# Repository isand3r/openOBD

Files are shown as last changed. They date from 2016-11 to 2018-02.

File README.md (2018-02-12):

# openOBD 
- An open-source vehicle telemetry system based on the [Raspberry Pi 0](https://www.raspberrypi.org/blog/raspberry-pi-zero) that supports OBD-2 and includes several sensors
- Originally developed as a UBC ECE [Capstone Project](https://www.ece.ubc.ca/courses/capstones) for [Mojio](https://www.moj.io/)

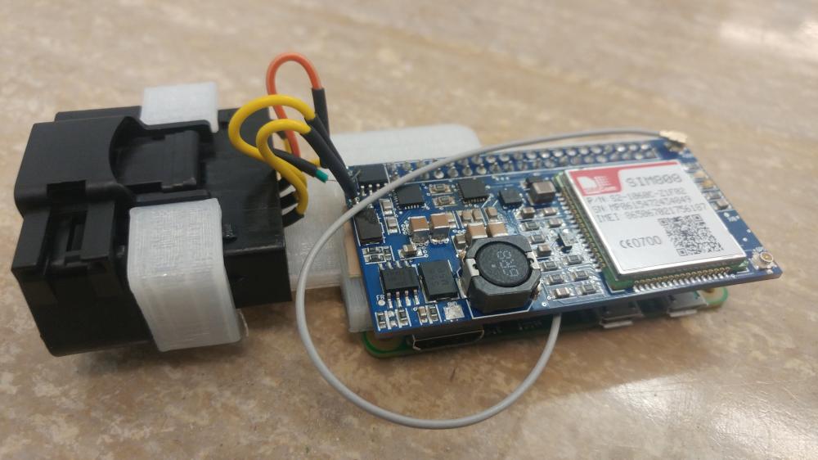
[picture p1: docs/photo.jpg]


### Setup

#### 1. Set up the Raspberry Pi

Follow this guide: https://www.raspberrypi.org/documentation/installation/installing-images/

The software requires a Linux-based operating system such as Ubuntu or Raspbian.

#### 2. Attach the board

Should be straightforward - attach the board using the GPIO socket with the board hanging overtop of your rpi.

#### 3. Clone this repository
On your raspberry pi, using the command line, run `git clone https://github.com/isand3r/openOBD`.

The Command line interface to get values from the sensors can be run using the file `app.py`

#### 4. Install dependencies

See the dependencies list at the bottom.

#### 5. Set up GSM (Optional)

Data readings can be saved to a file and uploaded via wifi, or for constant connectivity, there is a GSM module included.
All info on the GSM module can be found here: https://learn.adafruit.com/adafruit-fona-808-cellular-plus-gps-breakout/downloads#datasheets-and-app-notes

## Usage

### Command Line Application
```
cd software/openobd/
python3 app.py
```

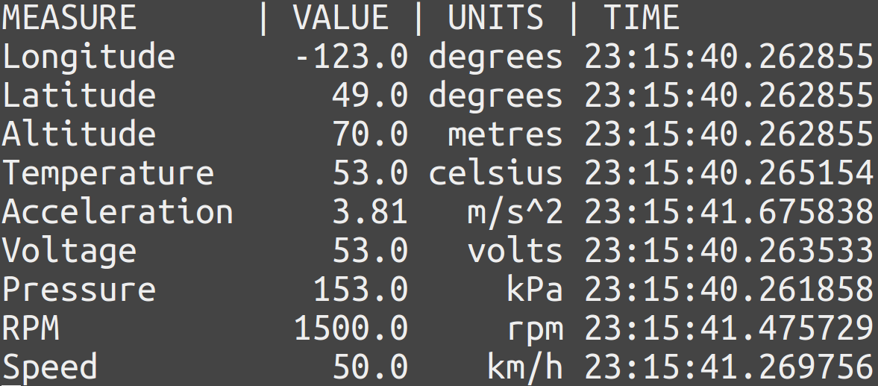
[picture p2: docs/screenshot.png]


### Configuration File
The configuration file `software/openobd/configuration/config.ini` (parsed using [configparser](https://docs.python.org/3/library/configparser.html)) is used to select the class that will be used for each sensor device (GPS, thermometer, etc). If mock devices are used (and if a few `import` lines are commented out in `software/openobd/app.py`), the command line application can be run on a regular PC without requiring the openOBD hardware.

### Tests
```
cd software/openobd/
python3 -m pytest
```

## Dependencies
Python packages (`pip3 install package-name`):
* `pytest` (doc.pytest.org/en/latest/)
* `RPi.GPIO` (https://pypi.python.org/pypi/RPi.GPIO)
* `PySerial` (https://pythonhosted.org/pyserial/)
* `python-can` (https://python-can.readthedocs.io)

## Contributors
* Nicholas Mulvenna
* Isaiah Thiessen
* Ehsan Ahmadi
* Kaibo Ma
* Rob Chartier

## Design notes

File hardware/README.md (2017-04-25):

### openOBD Hardware

The files in this folder are all contained in an Altium project. To view the files, you will need either Altium Designer or other compatible software (newer versions of [Eagle](http://www.autodesk.com/products/eagle/overview) can import Altium projects).

#### Circuit Schematics (Images) (coming soon)

#### B.O.M. (coming soon)

#### Programming the on board microcontroller

The on board microcontroller (ATtiny25) is wired to sense the vehicles battery voltage using its ADC. It can in turn controll a switch that can short the RUN pins on the Raspberry Pi Zero and wake/reboot it. The Raspberry Pi can communicate with the microcontroller through SPI interface in order to retreive data and/or reprogram it. This setup provides the user flexibility in implementing a custom power management. Following the instructions below, the ATtiny can be easily programmed:

* Compile your program using your favourite IDE/compiler ([Arduino IDE](http://www.arduino.org/downloads) or [Atmel studio](http://www.microchip.com/development-tools/atmel-studio-7) are options)
* Locate the generated .hex file and transfer it to the Raspberry Pi ([winSCP](https://winscp.net/eng/download.php) is a good tool)
* On the pi run 'sudo apt-get install avrdude' 
* [Configure](www.google,ca) avrdude using the following settings
1. 
    * id=pi0;
    * desc  = "Use the Linux sysfs interface to bitbang GPIO lines";
    * type = "linuxgpio";
    * reset = 18;
    * sck = 21;
    * mosi = 20;
    * miso = 19;

#### PCB Manufacturer

For our PCB, we used [pcbway.com](https://www.pcbway.com/). They are cheap, fast, and reliable. (images coming soon)

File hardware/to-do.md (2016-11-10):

## Hardware To-Do list

### Schematics

Additions:

  * Add gps chip & necessary power components
  * Add MEMs Sensor chip & necessary power components
  * Add a PCB layout

Changes:

  * Wire up the Mux
  * Wire up above components/chips once added

### Documentation

  * Create more documentation!

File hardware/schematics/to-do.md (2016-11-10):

## Hardware Schematics To-Do list

Additions:

  * Add gps chip & necessary power components
  * Add MEMs Sensor chip & necessary power components

Changes:

  * Wire up the Mux
  * Wire up above components/chips once added

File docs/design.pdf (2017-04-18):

# openOBD

# Automotive Telematics Unit

# Design - v3.3

## Authors:

## - Nicholas Mulvenna

## - Kaibo Ma

## - Ehsan Ahmadi

## - Isaiah Thiessen

Table of Contents

History of Revisions | 3
List of Figures and Tables | 6
1 - Introduction | 7
1.1 - How to Use this Document | .
2 - High-Level Architecture | 8
2.1 - Hardware Architecture | .
2.2 - Software Architecture | 10
3 - Low Level Design | 12
3.1 - Hardware Components | .
3.1.1 - Raspberry Pi Zero | .
3.1.2 - CAN Node | .
3.1.2A - MCP2515 CAN Controller | .
3.1.2B - TCAN332 CAN Transceiver | 13
3.1.3 - Power Supply | .
3.1.4 - Sensor Inputs | 14
3.1.4A - Sim808 GSM + GPS Cellular Module | .
3.1.4B - MPU6050 MEMs Motion Sensor Breakout Board | .

3.1.4C - ATtiny25 Microcontroller

3.1.5 - Printed Circuit Board (PCB) Design | .

3.1.6 - Hardware Enclosure | 15
3.2 - Software Components | .
3.2.1 - Python 3 | .
3.2.2 - Dependency Inversion Principle | 16
3.2.3 - Single Responsibility Principle | 17
4 - Conclusion | .
References | 18
Appendix I - On Board Diagnostics - OBD II | 20
Appendix II - Controller Area Network - CAN | .
Appendix III - Circuit Diagrams | 22
Appendix IV - Prototype Hardware Setup | 24
Appendix V - Sim808 Connections | 25
Appendix VI - MPU6050 Connections | .
Appendix VII - Printed Circuit Board - PCB | 26
Appendix VIII - PCB Layout Considerations | 27
Appendix IX - CAN Node Connections | 28
Appendix X - Live OBD2 Readings for Speed and RPM | 29
Appendix XI - Complete Hardware Setup | 30

History of Revisions

Version | Authors | Date | Changes
1.0 | Isaiah Thiessen Kaibo Ma Nicholas Mulvenna Ehsan Ahmadi | 2016-11-28 | Initial Draft
1.1 | Isaiah Thiessen | 2017-02-13 | - Updated Hardware Architecture diagram - Changed GPS section to reflect new chip being used - Updated Appendix V with new chip information
1.2 | Ehsan Ahmadi | 2017-02-13 | - New Can transceiver chip - Remove level shifter - New power supply - Added appendix VIII
1.3 | Isaiah Thiessen | 2017-02-13 | - Added component schematics in Appendix III (changed heading to Circuit Diagrams) - Added Appendix VII - PCB design schematic - Added Section 3.1.5 - PCB - Added Appendix IX for the CAN node pinout
1.4 | Nicholas Mulvenna | 2017-02-13 | - Updates software section with details on Manager and Configuration classes

| | | - Edited sections on dependency inversion and single responsibility principles - Removed abstraction layers section
2.0 | Isaiah Thiessen Ehsan Ahmadi Nicholas Mulvenna Kaibo Ma | 2017-02-13 | Final edits before v2 document release with some added figures to appendix
2.1 | Nicholas Mulvenna | 2017-02-26 | Corrects overlapping lines in high-level UML class diagram
3.0 | Nicholas Mulvenna | 2017-03-18 | - Style and wording in various sections - Describes the DeviceCollection class and removes references to the Shell class - Simplifies the high-level UML class diagram and adds new diagrams for the DeviceCollection and Manager classes
3.1 | Isaiah Thiessen | 2017-04-02 | - Justified amperage in power supply section - Fixed mistaken section heading in t.o.c. - New Hardware architecture Diagram

| | | - Edited section numbers - Added hardware enclosure section and appendix
3.2 | Ehsan Ahmadi | 2017-04-03 | - Updated power supply section to reflect new design - Added attiny25 section and schematic - Updated current/complete hardware setup - Updated list of tables & fig
3.3 | Nicholas Mulvenna | 2017-04-17 | - Changes to wording

List of Figures and Tables

Figure 2.0: High-Level Hardware Architecture | 8
Figure 2.1: UML class diagram focused on the App class | 10
Figure 2.2: UML class diagram focused on the DeviceCollection class | 11
Figure 2.3: UML class diagram focused on the Manager class | 11
Table 3.0: Python 2 vs Python 3 | 16
Figure A1.0: CAN bus diagram | 21
Figure A3.0: CAN Node Circuit Diagram | 22
Figure A3.1: SIM808 Circuit Diagram | .
Figure A3.2: Power Circuit Diagram | 22
Figure A3.3: MPU6050 Circuit Diagram | 23
Figure A3.4: ATtiny circuit diagram | 24
Figure A4.0: Prototype Hardware Setup | .
Table A5.0: Sim808 Module Connections | 25
Table A6.0: Motion Sensor Module Connections | .
Figure A7.0 - Printed Circuit Board Layout | 26
Figure A8.0 Buck converter topology and current loops | 27
Table A9.0: CAN Node to Raspberry Pi Connections | 28
Table A9.1: CAN Node to OBD-II Connections | .
Figure A10.0 - Live RPM readings from Revving Toyota Camry Engine | 29
Figure A10.1 - Log for Accelerating on Toyota Camry | 30
Figure A11.0 - Final setup assembled with the enclosure | .

1 - Introduction
This document is a comprehensive map of the technical design choices used in developing the Automotive Telematics Unit.

### 1.1 How to Use this Document

Aside from section 2, this document is of a highly technical nature. For both the technical or non-technical reader, section 2.0 - High-Level Architecture for hardware and software is the recommended starting point.

Following the high level discussion is a low-level technical breakdown of each component in section 3: Low-Level Design. Each subsection provides the reasoning behind the design choices, and guides the reader to a corresponding set of relevant appendices where various design artifacts are presented.
Subsection 3.1 covers hardware components, while 3.2 discusses software design.

2 - High-Level Architecture

2.1 - Hardware Architecture
Looking at figure 2.0, one can understand the hardware components involved as well as how each interacts within the design. Photos of the setup, in prototype stage are shown in Appendix IV, while Appendix XI shows the complete setup.

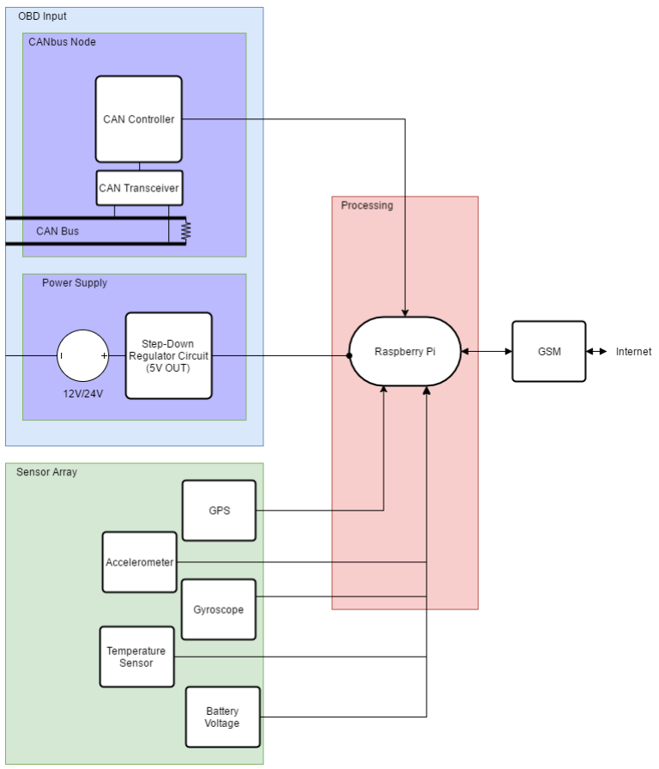
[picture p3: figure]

Figure 2.0: High-Level Hardware Architecture

On the following page is a brief description of the function of each component.

Processing Component:
A Raspberry Pi Zero interfaces with sensors and the OBD input block to collect, parse, and process the data.

OBD Input - CAN bus Component:
A CAN Bus device, following the CAN standard, includes a CAN controller and transceiver in order to read and write data to the CAN bus and perform arbitration and identification. It communicates with the processing block over a serial peripheral interface. The CAN bus is chosen as the focus of this project since every vehicle produced in the US since 2008 implements it.

OBD Input - Power Component:
Power for the processing block is drawn from the OBD port at 12 or 24 volts, depending on the vehicle. A power converter is used to regulate the power down to the levels required by the system

Sensors Component:
An array of onboard sensors for motion, temperature, and location readings.

A low level breakdown of each component is provided in section 3.1.

2.2 - Software Architecture
Our architecture, described in the UML class diagram in figure 2.1, is based on abstract classes. Our main executable class App instantiates our concrete device classes (based on a configuration file) and aggregates them in a DeviceCollection instance. Also, it instantiates the Manager class which automatically reads, interprets, and displays data. App provides Manager with the DeviceCollection (an implementation for an IDeviceCollection) to allow it to read data from our sensors and the OBD port. Since our major components are all constructed by App, Manager and DeviceCollection depend on abstract classes instead of being coupled to specific implementations.

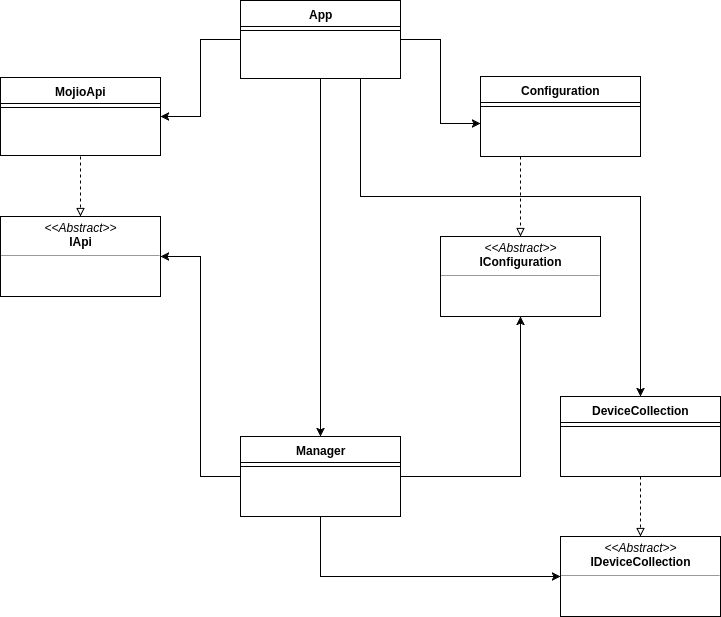
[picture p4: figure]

Figure 2.1: UML class diagram focused on the App class

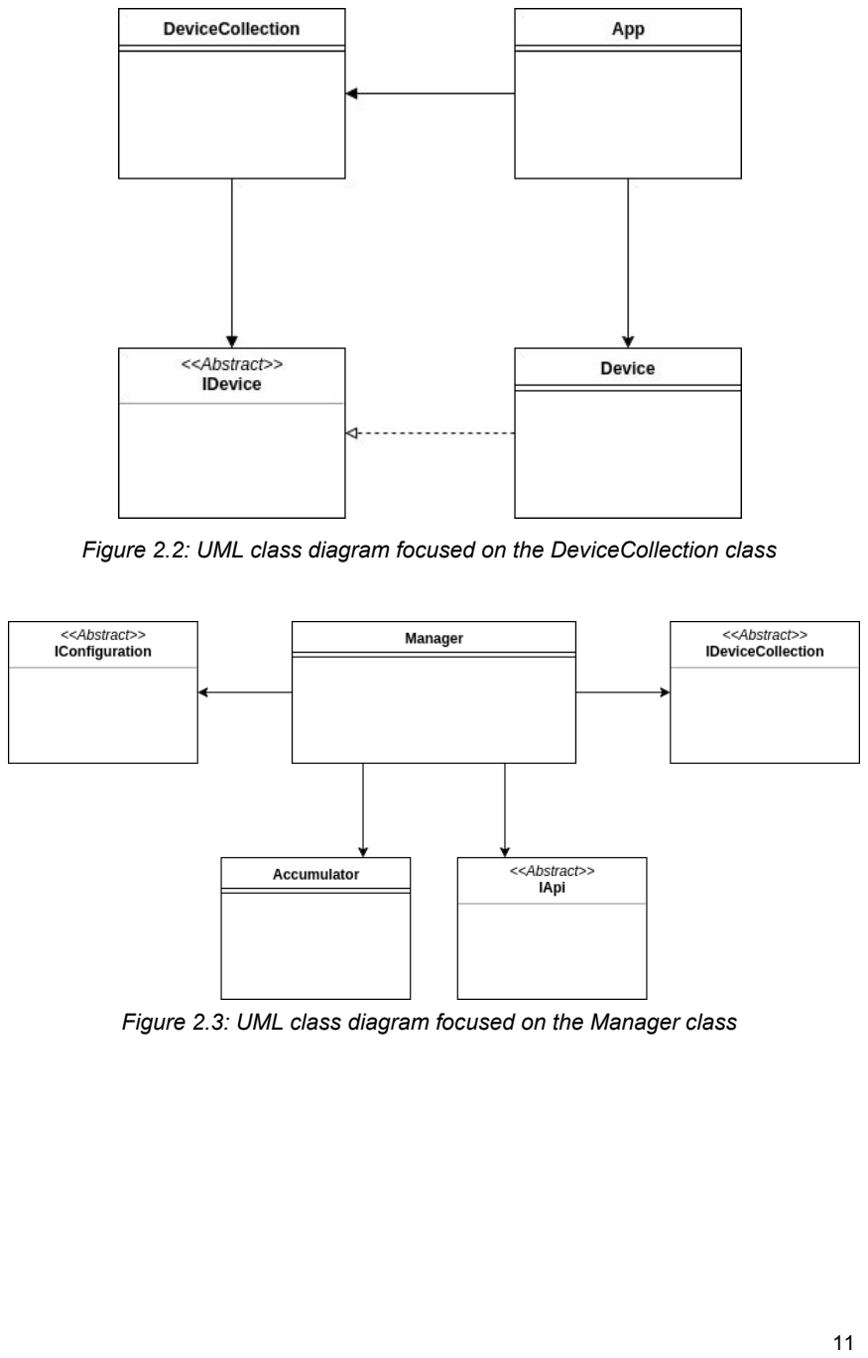
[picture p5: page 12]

Figure 2.2: UML class diagram focused on the DeviceCollection class

Figure 2.3: UML class diagram focused on the Manager class

3 - Low-Level Design
The next sections go into detail around the design choices of each component. In order to justify these choices, references are made to functional specifications (coded FS##), non-functional specifications (coded NS##), and constraints (coded C##) which are defined in the accompanying requirements document.

3.1 - Hardware Components

3.1.1 - Raspberry Pi Zero
The Raspberry Pi Zero is a small, inexpensive single board computer used as the main processing unit of the system. It runs a 1GHz ARM processor, supported by 512MB of ram, providing plenty of processing power. An array of GPIO pins with SPI, I2C and UART capabilities makes interfacing with sensors and hardware components very easy and satisfies the FS02 specification. The Pi Zero is widely adopted by the open source community globally and extensively documented. This means open source libraries are available for almost any application and support is readily accessible resulting in short development ramp-up time. The Pi Zero runs Raspbian Jessie (A Debian Linux based operating system optimized for the Pi) which provides a terminal interface to the user over USB, satisfying the FS03 specification.

3.1.2 - CAN Node
The CAN node implements the standard CAN communication protocol and facilitates interfacing with the CAN bus and satisfying FS01. It gives the system access to the vehicle’s on board diagnostics (OBD-II) network which can provide information about and control over different components of the vehicle. The CAN node is comprised of a CAN controller, CAN transceiver and two level converters A detailed description of the OBD-II and CAN are provided in appendix I and II respectively. See Appendix III for a circuit diagram and pinout information.

3.1.2A MCP2515 CAN Controller
As detailed in Appendix I the CAN communication protocol implements error correction, bit timing, and synchronization and arbitration of different nodes on the

CAN bus. To achieve this, complex message frames are used to transmit data on the can bus. The CAN controller acts as a configurable node on the can bus and deals with the low level implementation of the CAN protocol. It extracts the data contained in a CAN message frame received from the bus and provides it to the processor over an SPI interface. It can also convert data provided by the processor and converts it to a CAN message frame that is ready to be transmitted on the bus. This chip was chosen as it provides the best combination of functionality and low cost, and is commonly used in the design of CAN devices. [7]

3.1.2B TCAN332 CAN Tranceiver
CAN message frames provided by the can controller as a serial signal of ones and zeros is converted to a differential signal and transmitted on the CAN bus (appendix
I) by the CAN transceiver. At the same time differential signals received on the can bus are converted to a serial signal and provided to the CAN controller. This chip was chosen as it provides the best combination of functionality and low cost. Since the chip uses 3.3 volts, it uses less power the need for level shifting between it and the controller is eliminated resulting in a smaller pcb footprint.[8]

3.1.3 - Power Supply
An LMR16030 Buck controller, combined with external components (7 capacitors, Inductor, a Diode and a few resistors) is used as the power supply. The power supply is designed for a wide input voltage range of 6V to 40V. It steps down voltage from the OBD port (typically 12V or 24V) to a constant 5V to power the Pi Zero which in turn powers all the other components with the exception of the sim808 (powered through a 5V to 4V linear regulator), satisfying the FS07 requirement. The power supply is designed to provide up to 3A (15W). 1A is required by the Pi to function reliably [16] leaving enough power for the sim808 chip which peaks at 2A. The LMR16030 is a flexible converter with an internal high side mosfet running at 500KHz, providing the ability to use very small external components, saving both space and cost. A switching supply is used instead of a linear regulator in order to reduce power losses and prevent excessive heating, in line with C04 and C06.

3.1.4 - Sensor Inputs

3.1.4A - Sim808 GSM + GPS Cellular Module
The Sim808 module was chosen in order to reduce footprint consumption for the PCB design, while retaining ease-of-setup and short development overhead. This component provides all necessary GPS location functionality over UART to the processing unit in a “plug-and-play” fashion at relatively low cost, in addition to providing 2G Cellular network connectivity. See Appendix V for pinout information and links to official documentation.

3.1.4B - MPU6050 MEMs Motion Sensor Breakout Board
The MPU6050 was chosen with the same justifications as the Adafruit GPS board discussed above. It provides accelerometer, gyroscope and temperature data to the processing unit over I2C. See Appendix VI for pinout information and links to official documentation.

3.1.4C - ATtiny25 Microcontroller
One of the limitations of the Pi is that it does not include an ADC (analog to digital converter). To overcome this limitation, a cheap ATtiny25 microcontroller was added to the design. Some desired functions of the ATtiny include ADCs, SPI communication and general purpose GPIOs. The ATtiny senses the voltage of the vehicle’s battery and makes it available to the Pi over SPI. It is also able to safely shut down and turn on the Pi. The ATtiny runs independent of the Pi, however, it can be programmed on-the-go using the Raspberry Pi, making it a very flexible and customizable power management solution.

3.1.5 - Printed Circuit Board (PCB) Design
The design schematic for the PCB layout is included in Appendix VII. It was designed to approximately match the form factor of the Raspberry Pi Zero in order to minimize the overall size of the device. Further technical information is included with the schematic. All values for items such as minimum hole size, trace size and spacing, were chosen in order to meet the capabilities of the PCB manufacturer while achieving the desired form factor. Since the PCB combines a high frequency switching power supply and multiple high speed communication devices in a small area. Strict guidelines were followed when laying out the board in order to ensure signal integrity and reliable communication. These guidelines were It is highly recommended to follow these guidelines detailed in appendix X when reproducing the PCB with minor modifications. The pcb has an exposed ground pad as well as several test points for the output and feedback pin of the power supply, 4V linear regulator, SPI data lines, as well as multiple power rails of the Sim808 chip. As a result, an oscilloscope can be easily attached in order to debug the circuit if need be.

3.1.6 - Hardware Enclosure
Given that this is an open-source, modular project, an example hardware enclosure is shown in Appendix XI. This part’s design would be modified depending on changes made to the hardware.
The example design was chosen for simplicity and ease of fabrication. It holds all of the components together and provides a grip point for ease of setup or removal.

### 3.2 Software Components

3.2.1 - Python 3
Python 3 is a robust and popular language. There is significant community-based documentation and a wide variety of available modules. Python also includes convenient Cmd and ConfigParser classes that we use for debugging and in our Configuration class implementation.

In addition, our team has picked Python 3 over Python 2. In the following Table, key main differences between the two versions and why we believe Python 3 is more advantageous:

Python 2.7.12 | Python 3.5.2
- Legacy - Will have no more major feature releases | - Long term supported version - Present and future of the language - Ongoing expansions and support for the language

Table 3.0: Python 2 vs Python 3

3.2.2 - Dependency inversion principle
In object oriented programming, there are various types of branches of design principles. One of which is dependency inversion principle. This refers to the decoupling between different software modules. In other words, two different libraries are not dependent on each other. When following this principle, higher level classes/modules will be independent from lower level modules implementation details. For our project, that means that our Manager class (through its DeviceCollection) depends only on abstract classes for devices. This allows different device class implementations to be substituted without requiring any changes to classes such as the DeviceCollection, MojioApi, and Manager. In future prototypes and products, it will be easier to change hardware modules (such as our GPS or sensors) because only the module/class responsible for that hardware’s drivers need to be modified and not the entire application. Software modules can be extracted and placed in a whole new application without worrying about dependencies of a particular module being extracted. This allows a “plug and play” convention for mixing and matching modules. For example, we could extract the modules for GPS and import them in a completely unrelated project that uses the same GPS hardware.
Our architecture is based on abstract classes to fulfill requirement NS02. Python supports multiple inheritance so it does not have Java-style interfaces. To ensure that they cannot be instantiated, our abstract classes extend the abc.ABC class.[14]

This is equivalent to an interface-oriented architecture because our abstract classes do not contain implementations.

3.2.3 - Single responsibility principle
This is a principle in object oriented design which states that modules, classes, and functions should only have one responsibility or purpose within the software. The functionality should be completely encapsulated within the class or function. For example, the device classes are responsible only for taking readings from the hardware modules but not for working with those readings. Similarly, the Manager class decides when to take readings and displays them to the user but does not directly interact with the hardware. Indirectly, this principle enforces the dependency inversion principle as well.

4 - Conclusion
The overall design and theme of the product is based on community learning. Both hardware and software use open source solutions and libraries. As a result our project will also be open source with a public repository for anyone else to access.

Our hardware and software are tailored for customizability. The hardware can be interchanged with relative ease because the software adopts the single responsibility and dependency inversion principles. This allows modularity and independence of different modules and devices like OBD and GPS. Hardware can be swapped out for faster and even better devices with minimal changes to the software.

References
[1] Guttag, John V. (2013-01-18). Introduction to Computation and Programming Using Python (Spring 2013 ed.). Cambridge, Massachusetts: The MIT Press. ISBN (https://en.wikipedia.org/wiki/International_Standard_Book_Number) 9780262519632. (https://en.wikipedia.org/wiki/Special:BookSources/9780262519632)
[2] "Abstract Methods and Classes". (http://docs.oracle.com/javase/tutorial/java/IandI/abstract.html) The Java™ Tutorials. Oracle. Retrieved 27 November 2016.
[3]"Dissection of the Single Responsibility Principle - dylanwilson.net", Dylanwilson.net, 2016. [Online]. Available: http://www.dylanwilson.net/dissection-of-the-single-responsibility-principle. [Accessed: 27- Nov- 2016].
[4] "Dependency Inversion Principle | Object Oriented Design", Oodesign.com, 2016.
[Online]. Available: http://www.oodesign.com/dependency-inversion-principle.html. [Accessed: 27- Nov- 2016].
[5] “Should I use Python 2 or Python 3 for my development activity?”, wiki.python.org, 2016. [Online]. Available: https://wiki.python.org/moin/Python2orPython3 [Accessed: 27- Nov- 2016].
[6] “MPU-6000 and MPU-6050 Product Specification Revision 3.4”, Sparkfun, 2016. [Online]. Available:
http://43zrtwysvxb2gf29r5o0athu.wpengine.netdna-cdn.com/wp-content/uploads/2015/02/MPU-6000-Datasheet1.pdf (http://43zrtwysvxb2gf29r5o0athu.wpengine.netdna-cdn.com/wp-content/uploads/2015/02/MPU-6000-Datasheet1.pdf) [Accessed: 27-Nov-2016]
[7] “Stand-Alone CAN Controller with SPI Interface”, microchip.com, 2016. [Online]. Available: http://ww1.microchip.com/downloads/en/DeviceDoc/21801G.pdf [Accessed: 27-Nov-2016]
[8] “High-Speed CAN Transceiver”, microchip.com, 2016. [Online].
Available: http://ww1.microchip.com/downloads/en/DeviceDoc/20005167C.pdf [Accessed: 27-Nov-2016]
[9] “Adafruit Ultimate GPS Breakout - 66 Channel W/10 HZ Updates”, adafruit.com, 2016. [Online]. Available: https://www.adafruit.com/product/746 [Accessed: 27-Nov-2016]
[10] “Triple Axis Accelerometer Gyro Breakout MPU6050 v12”, sparkfun.com, 2016. [Online]. Available:

https://cdn.sparkfun.com/datasheets/Sensors/IMU/Triple_Axis_Accelerometer-Gyro_Breakout_-_MPU-6050_v12.pdf (https://cdn.sparkfun.com/datasheets/Sensors/IMU/Triple_Axis_Accelerometer-Gyro_Breakout_-_MPU-6050_v12.pdf) [Accessed: 27-Nov-2016]

[11] “GPS_FGPMMOPA6H_v0.3”, adafruit.com, 2016. [Online]. Available:

https://cdn-learn.adafruit.com/assets/assets/000/022/494/large1024/gpssch.png?142153647 5 (https://cdn-learn.adafruit.com/assets/assets/000/022/494/large1024/gpssch.png?1421536475) [Accessed: 27-Nov-2016]
[12] “Introduction to the Controller Area Network (CAN)”, ti.com, 2008. [Online]. Available: http://www.ti.com/lit/an/sloa101a/sloa101a.pdf [Accessed: 27-Nov-2016]
[13] “On-board diagnostics”, Wikipedia, The Free Encyclopedia, 2016. [Online]. Available: https://en.wikipedia.org/wiki/On-board_diagnostics#SAE_standards_documents_on_OBD-II (https://en.wikipedia.org/wiki/On-board_diagnostics#SAE_standards_documents_on_OBD-II) [Accessed: 27-Nov-2016]
[14] "Abstract Base Classes in Python – dbader.org", Dbader.org, 2016. [Online]. Available: https://dbader.org/blog/abstract-base-classes-in-python. [Accessed: 28-Nov-2016].
[15] “Switching Power Supply PCB Layout Considerations – Towards a Better Switcher”, optimumdesign.com, 2017/ [online]. Available: http://blog.optimumdesign.com/switching-power-supply-pcb-layout-considerations-to wards-a-better-switcher. (http://blog.optimumdesign.com/switching-power-supply-pcb-layout-considerations-towards-a-better-switcher) [Accessed: 13-Feb-2016]
[16] “Power Supply”, raspberrypi.org, 2017 / [online]. Available: https://www.raspberrypi.org/documentation/hardware/raspberrypi/power/README.m d (https://www.raspberrypi.org/documentation/hardware/raspberrypi/power/README.md) [Accessed: 02-Apr-2016]
[17] “Program an AVR...Raspberry Pi GPIO”, Adafruit.com, 2017 / [Online]. Available:
https://learn.adafruit.com/program-an-avr-or-arduino-using-raspberry-pi-gpio-pins/ov erview (https://learn.adafruit.com/program-an-avr-or-arduino-using-raspberry-pi-gpio-pins/overview) [Accessed: 03-Apr-2016]

Appendix I - On Board Diagnostics - OBD-II
Onboard diagnostics (OBD) is a computer based system built into all 1996 and later light-duty vehicles and trucks to monitor and in newer vehicles control their different sub components. The OBD-II standard defines the OBD II diagnostic connector and 5 standard communication protocols for interfacing with it, one of which is the CAN protocol and is standard on all US produced vehicles since 2008. The CAN is described in detail in appendix II and is the target protocol for this project. For more information on the OBD, see [13].

Appendix II - Controller Area Network - CAN
A Controller Area Network is defined by its two components described in this appendix, the CAN bus and the CAN communication protocol (ISO-11898). This appendix is based on ti’s introduction to CAN document [12] and introduces a few basics of the CAN in order to demonstrate its complexity. This complexity is handled by the MCP2515 CAN controller, however, a hardware designer needs to be aware of these complexities in order to use the controller.
The CAN bus is a multi-master, message broadcast system that specifies a
maximum signaling rate of 1 megabit per second (Mbps). As shown in figure A1, multiple masters (nodes) are connected to a differential line that is terminated by two resistors. Signals on the CAN bus are differential and highly immune to noise. A logic high is dominant and represents a 0, while a logic-low is recessive and represents a
1. This means that a 0 written on the bus by one node, overwrites a 1 that is simultaneously written by another node. This property is key to arbitration process described in the communication protocol. For effective communication, every node on the bus must agree to uniform nominal bitrate.

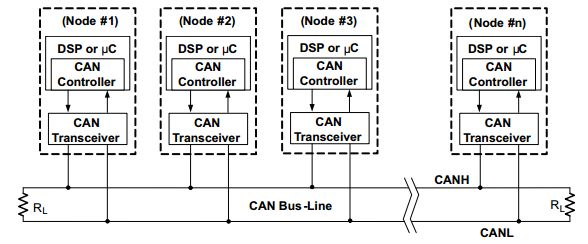
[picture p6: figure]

Figure A1.0: CAN bus diagram

The CAN communication protocol is a carrier-sense, multiple-access protocol with collision detection and arbitration on message priority (CSMA/CD+AMP). Since every node on the bus is a master and has read/write capability, each node on a bus must wait for a prescribed period of inactivity before attempting to send a message. Usage of the bus granted to the node that is transmitting a message with the highest priority. Messages are identified using a 11-bit (standard CAN) or 29-bit (extended CAN) identifier which allows for up to 2048 or 537 million unique prioritization levels respectively. Since the transmitted messages are broadcasted to all the nodes, the identifier can also be used to target the messages to specific nodes. The receiving nodes perform error checking on the message and requests a resend if failed. Due to different delays times and different clock speeds across the CAN, The actual bitrate of the messages is dynamically adjusted slightly above or below the nominal bit rate to keep the nodes synchronized and resolve errors

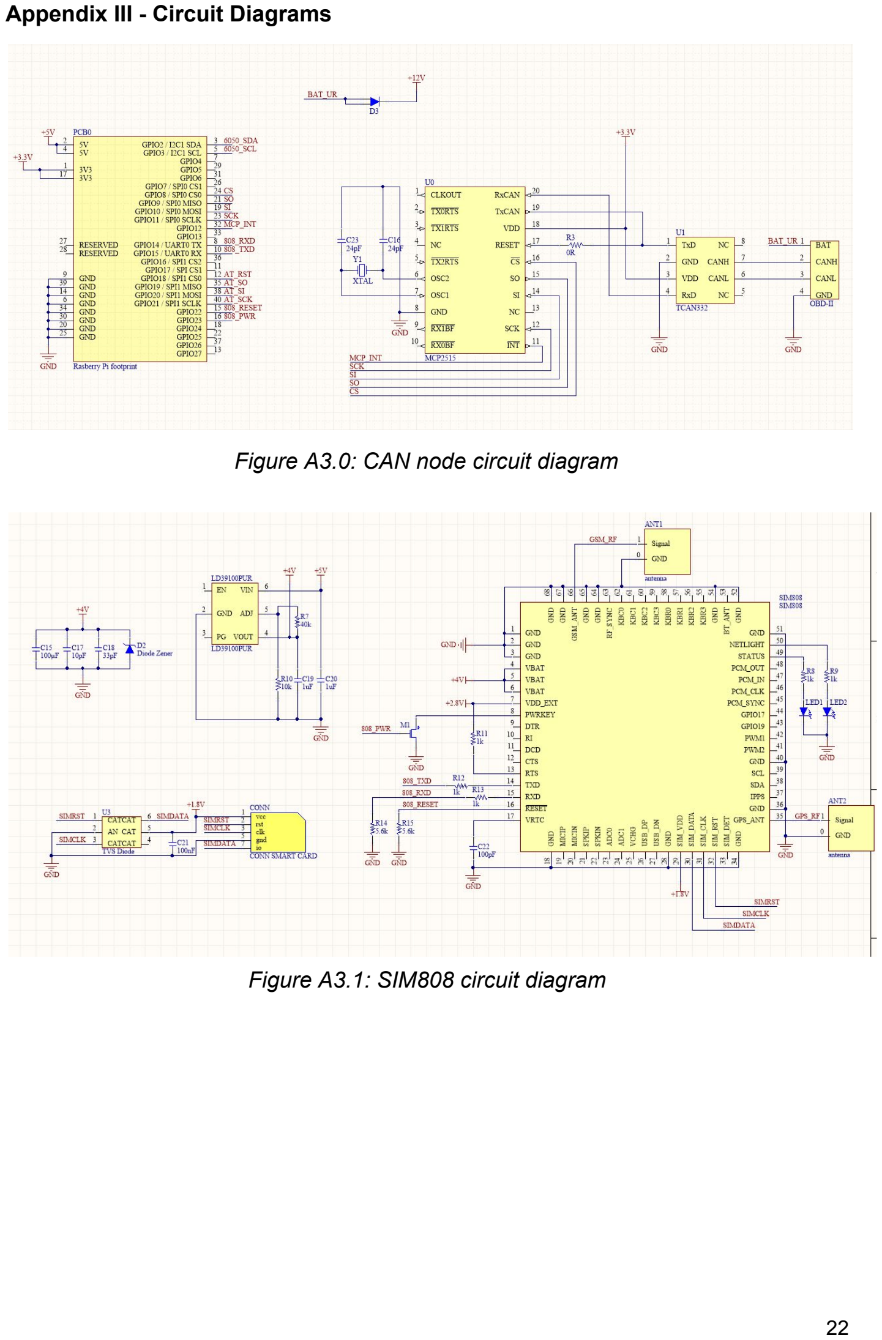
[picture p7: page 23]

Appendix III - Circuit Diagrams

Figure A3.0: CAN node circuit diagram

Figure A3.1: SIM808 circuit diagram

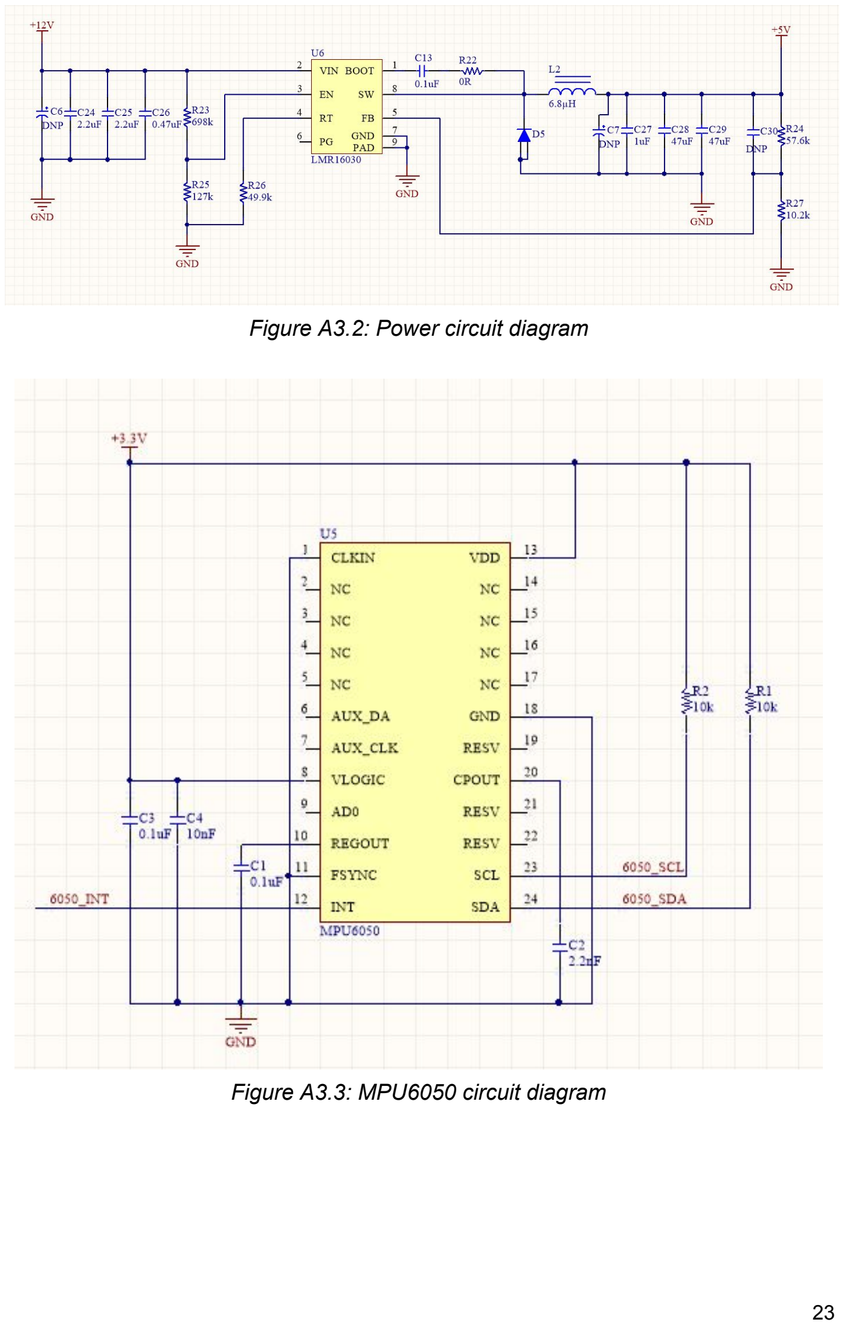
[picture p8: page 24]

Figure A3.2: Power circuit diagram

Figure A3.3: MPU6050 circuit diagram

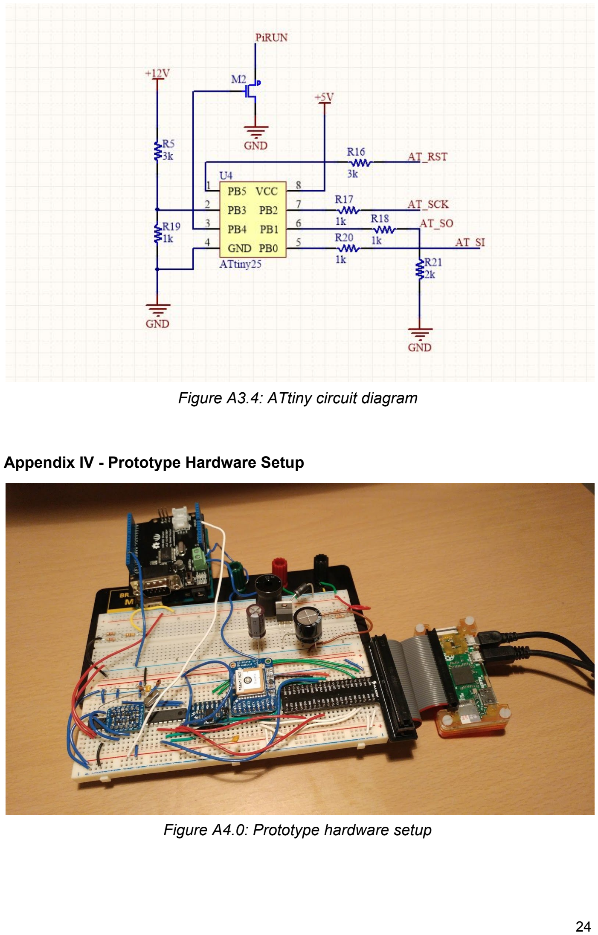
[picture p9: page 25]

Figure A3.4: ATtiny circuit diagram

Appendix IV - Prototype Hardware Setup

Figure A4.0: Prototype hardware setup

Appendix V - Sim808 Connections https://www.adafruit.com/product/2637

Sim808 Connections

Sim808 Pin | Raspberry Pi pin #
RESET | 15
PWR | 16
GND | 6
VIN | 2
TXD | 10
RXD | 8
Table A5.0: Sim808 module connections

Appendix VI - MPU6050 Connections

https://cdn.sparkfun.com/datasheets/Sensors/IMU/Triple_Axis_Accelerometer-Gyro_Breakout_-_MPU-6050_v12.pdf (https://cdn.sparkfun.com/datasheets/Sensors/IMU/Triple_Axis_Accelerometer-Gyro_Breakout_-_MPU-6050_v12.pdf)

MPU6050 Connections

MPU6050 Pin | Raspberry Pi pin #
VCC | 1
GND | 6
SCL | 5
SDA | 3
Table A6.0: Motion sensor module connections

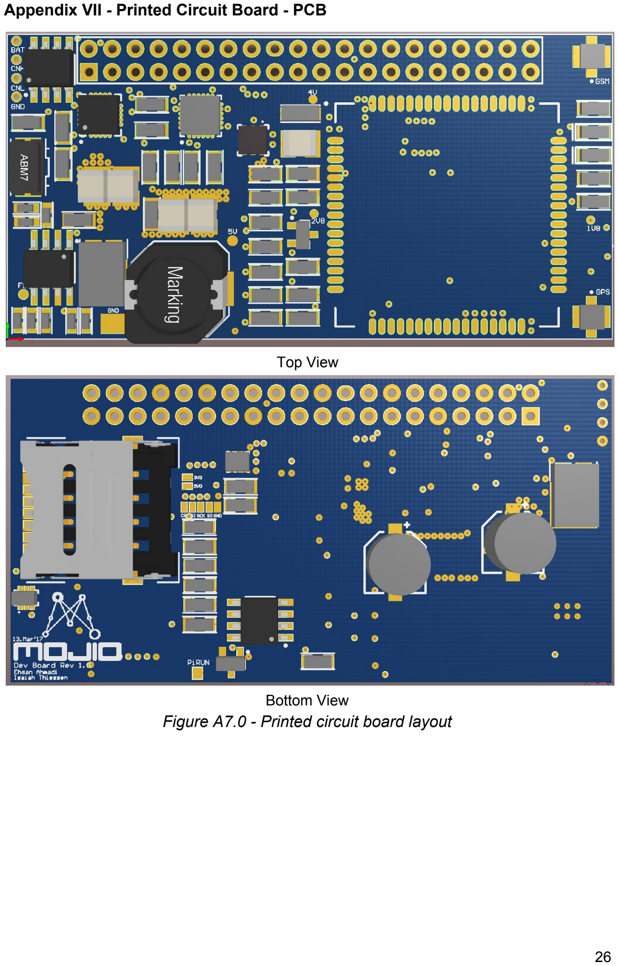
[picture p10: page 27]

Appendix VII - Printed Circuit Board - PCB

Top View

Bottom View
Figure A7.0 - Printed circuit board layout

Appendix VIII - PCB Layout Considerations

High frequency switching power supplies are efficient and flexible compared to linear regulators, however they can be a significant source of EMI (Electro-Magnetic Interference) which can corrupt low power signals in their vicinity resulting in a malfunctioning board. EMI generated by switching power supplies can be significantly reduced if the following guidelines are followed when laying out the design. The guidelines refer to figure A8.0 which shows the main AC and DC current loops in the buck converter topology.

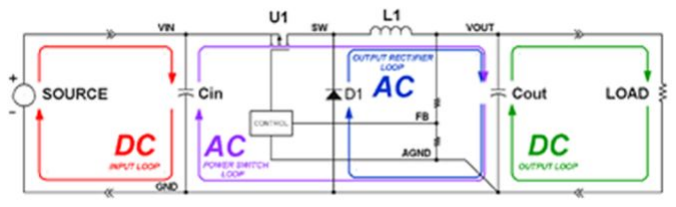
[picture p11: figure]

Figure A8.0 - Buck converter topology and current loops [15]

- The SW node carries a high frequency AC current of large magnitude and acts as an antenna, the main source of EMI. A good layout should minimizes the length of the switch node.
- For the AC currents, the length should be minimized with the forward paths on the top layer and the return paths on the bottom layer forming a closed loop. A ground plane on the bottom layer facilitates this.
- Lots of vias have to be used between layers for a low impedance path.
- The ground plane under the power supply should be separated from the signal ground(for the rest of the board) using a small connection in order to keep the high frequency currents contained.
- All the AC and DC loops should be laid out using polygons to ensure low impedance.
- The power supply should be placed as far as possible from sensitive signals, especially the GPS and GSM antennas.

Appendix IX - CAN Node Connections

To Raspberry Pi

Circuit Pin | Raspberry Pi Pin #
5V0 | 2
3V3 | 1
GND | 6
RESET | GND
CS | 24
SO | 21
SI | 19
STBY | Not currently Used
Table A9.0: CAN Node to Raspberry Pi Connections

OBD Connections

Circuit Pin | OBD Port Pin #
CAN HIGH | 6
CAN LOW | 14
BAT +12V | 16
GND | 5
Table A9.1: CAN Node to OBD-II Connections

Appendix X - Live OBD2 Readings for Speed and RPM

The following two images are from accelerating a Toyota Camry 2015 from resting and parking to about 21km/h.

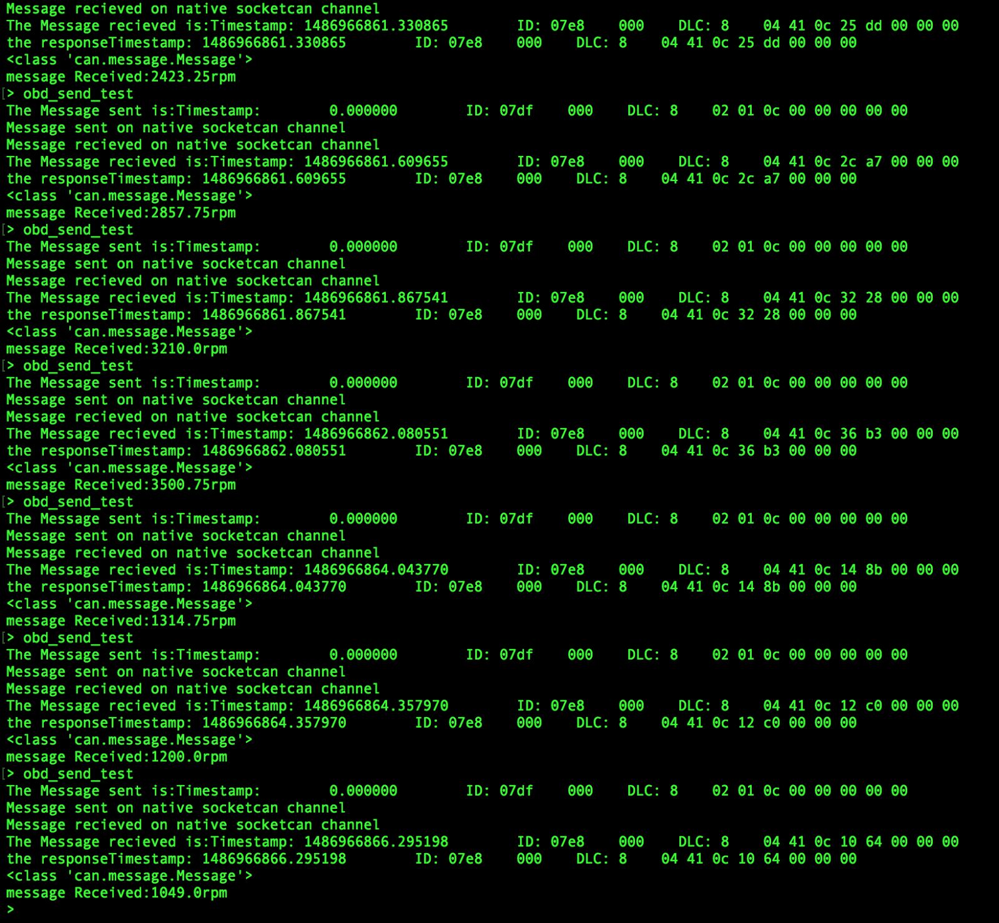
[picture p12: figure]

Figure A10.0 - Live RPM readings from revving Toyota Camry engine

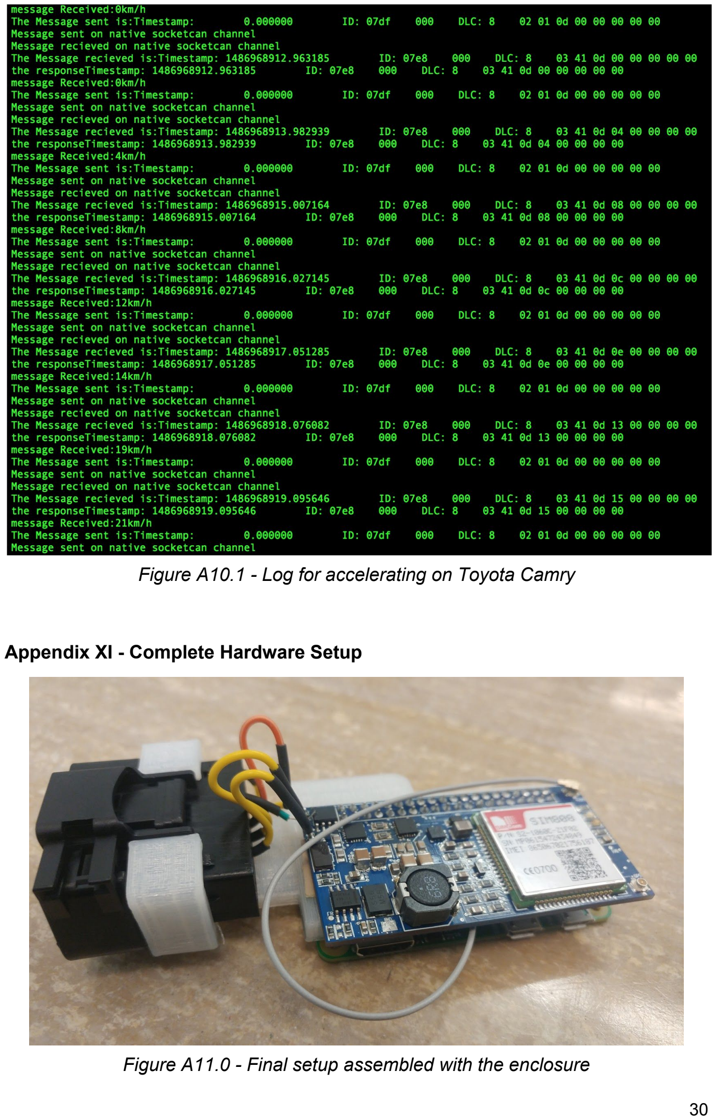
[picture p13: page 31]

Figure A10.1 - Log for accelerating on Toyota Camry

Appendix XI - Complete Hardware Setup

Figure A11.0 - Final setup assembled with the enclosure

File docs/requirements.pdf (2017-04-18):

# openOBD

# Automotive Telematics Unit

# Requirements - v3.1

## Authors:

## - Nicholas Mulvenna

## - Kaibo Ma

## - Ehsan Ahmadi

## - Isaiah Thiessen

Table of Contents

History of Revisions | 2
List of Tables and Figures | 3
List of Technical Terms | .
1 - Introduction | 4
1.1 - How to Use this Document | .
2 - Context & Background | 5
3 - Domain | 6
4 - Goal | 7
5 - Functional Specifications | 8
6 - Non-Functional Specifications | 9
7 - Constraints | 10
References | 11

History of Revisions

Version | Authors | Date | Changes
1 | Isaiah Thiessen Kaibo Ma Nicholas Mulvenna Ehsan Ahmadi | 2016-11-28 | Initial Draft
2 | Nicholas Mulvenna | 2017-02-07 | - Removes original NS06 (encryption) and replaces it with original NS07 - Reworded C07
3 | Isaiah Thiessen | 2017-04-05 | - Grammar, wording, and formatting
3.1 | Nicholas Mulvenna | 2017-04-17 | - Wording and length

List of Tables and Figures

Table 5.0 - List of Functional Specifications | 8
Table 6.0 - List of Non-Functional Specifications | 9
Table 7.0 - List of Constraints | 10

List of Technical Terms

Term | Definition
Internet of Things | The network of internet connecting everyday devices and appliances, enabling benefits such as home automation.
Connected Car | A vehicle enhanced with “Internet of Things” technology. [1]
Dependency Inversion Principle | A software design principle in which classes depend on abstractions. [2]
Single Responsibility Principle | A software design principle in which each class has only one responsibility which is its only reason to change. [3]
Onboard Diagnostics Port (OBD) | A standard port located under the steering wheel in North American vehicles, used to communicate with the vehicle’s internals for diagnostic purposes.

1 - Introduction

This document states the purpose, scope, and requirements for the Automotive Telematics Unit project.

1.1 - How to Use this Document
Most of the content presented here will be high level. A conceptual understanding of software and hardware design will be helpful to the reader for the last 3 sections on specifications and constraints.

Less technical readers may be directed to use the following notes:
- For an overview of the purpose of this project, see section 2: Context & Background on the next page.
- For coverage of the scope and goals, see sections 3: Domain and 4: Goal, starting from page 5.

Otherwise,
- Section 5: Functional Specifications describes the capabilities and services that must be delivered by the product (page 8).
- Section 6: Non-Functional Specifications discusses key attributes the product must exhibit (page 9).
- Section 7: Constraints lists cost, safety, and other compliance requirements (page 10).

This is a living document and changes must be recorded in the table on the previous page.

2 - Context & Background
Mojio provides a cloud software service that interfaces with connected car applications. They currently supply an automotive telematics unit that reads from the OBD-2 (On-Board Diagnostics) port of vehicles and on board sensors to feed behavioural and diagnostics data to the platform, typically done through a constant connection to a cellular network. Currently the production and design of the device is outsourced to a third-party vendor.

The primary objective given for this project is to develop a prototype telematics unit in order to give the company valuable insights into what is involved in developing an OBD device “in-house”. This device is a vital source of data for the organisation’s software platform and associated applications. Transitioning the design in-house could enable extended customisation of features to meet more customer needs, advanced modularity of design, and the potential for cost reduction for Mojio and consumers.

3 - Domain
In terms of market sectors, the Automotive Telematics Unit falls into the consumer electronics domain.

The product aims to follow Mojio’s mission statement “Driven Towards a more connected world”, in that enables customers to know the health and status of their vehicles at all times. [4]

This caters to a growing market of consumers who wish to be able to integrate their car into the “internet of things”. Our sensor hub dongle is in a small venture for automotive technologies as there are not many competitors. This sector is expected to see major growth as consumers seek to have more and more connected devices all on a single platform. [5]

4 - Goal
In order to take advantage of and grow the “internet of things” market offerings, this product is aimed at a newer niche for connected car enthusiasts. The automotive industry has traditionally been relatively slow to adopt advances in computer technology. Many new tech companies or startups are looking into the industry as a result, and need to cater to legacy models of vehicles. This product aims to bridge the gap between legacy technology and today’s connected world, but also facilitate learning for Mojio.

Our client and partner, Mojio, seeks a prototype able to connect a large variety of cars to their cloud platform, allowing vehicles to be monitored remotely through a computer or smartphone. For example, a car owner could monitor their car’s location, speed, temperature, and health of the vehicle from their mobile devices no matter how far away they are from their car.

The project’s goal is the following:
The company will have an inhouse solution and knowledge to maintain their product for future development. It will be more customizable and modular in order to further meet customer needs while remaining cost effective and efficient.

Aligned with Mojio’s purpose and mission statement, the project will ultimately improve on connected car technology, which promotes safety through data on the status and health of vehicles.

5 - Functional Specifications
With the project’s goals in mind, the product is subject to meeting the following functional specifications to fulfill Mojio’s user needs:
ID# | Description
FS01 | The system is capable of reading and requesting data from the OBD port of a vehicle.
FS02 | The system is capable of reading on-board sensors including (but not limited to): ▸ Accelerometer ▸ GPS ▸ Gyroscope ▸ Temperature
FS03 | The system can output the data to a terminal window, or similar human-readable interface.
FS04 | The system includes an API to facilitate interfacing with the device.
FS05 | The system can return or log data in a format which is compatible with the Mojio platform.
FS06 | The system has the ability to interface with the Mojio cloud platform.
FS07 | The system can be powered from a vehicle’s OBD port.

Table 5.0 - Functional Specifications List

The Functional Specification ID#’s used here may be referenced in other documents and are subject to the details recorded in this document only.

A feature-based approach was chosen rather than a use-case model because the project is focused on a product that will be used in further development by developers rather than being marketed directly to consumers.

6 - Non-Functional Specifications
In order to allow Mojio to take advantage of a more customizable device, the product must satisfy the following non-functional specifications including software quality attributes such as security, modularity, and portability.
ID# | Description
NS01 | Software must be portable across different types of single-board computers.
NS02 | Software classes must follow the dependency inversion principle.
NS03 | Software classes must follow the single responsibility principle.
NS04 | Software classes that are not directly related to interacting with the hardware modules (eg. sensors and GPS) must be testable without requiring the hardware modules as part of the test.
NS05 | Software architecture will be able to maintain interoperability and be able to interface with legacy technology
NS06 | Software and Hardware will be documented such that Mojio developers can reproduce and modify the product to further fit their needs if necessary.

Table 6.0 - Non-Functional Specifications List

The Non-Functional Specification ID#’s used here may be referenced in other documents and are subject to the details recorded in this document only.

7 - Constraints
Our product must satisfy the constraints in the table below, which help define the scope of the project in that they affect our software and hardware implementation and influence the overall design.
ID# | Description
C01 | The design cannot incorporate off-the-shelf OBD protocol readers that abstract away the protocols and their complexities (e.g. no black box components).
C02 | The project is constrained to UBC’s provided budget ($650)
C03 | The design must not violate any OBD standards in how it communicates with the protocols
C04 | The designed system must be safe to use and not present any health or other risks to the user.
C05 | The final prototype device must have a form factor which fits conveniently in the OBD port in a significant number of vehicles.
C06 | The product, when connected to a vehicle, must not damage any of the vehicle’s electronics or computer systems.
C07 | The system must be convenient to adapt to hardware changes (eg new sensors or vehicle protocols) with minimal software changes.

Table 7.0: List of Constraints

The Constraint ID#’s used here may be referenced in other documents and are subject to the details recorded in this document only.

8 - References
[1]"The Open Connected Car Platform", Mojio, 2016. [Online]. Available: https://www.moj.io/connected-car-platform/. [Accessed: 27- Nov- 2016].
[2]"Dependency Inversion Principle | Object Oriented Design", Oodesign.com, 2016.
[Online]. Available: http://www.oodesign.com/dependency-inversion-principle.html. [Accessed: 27- Nov- 2016].
[3]"Dissection of the Single Responsibility Principle - dylanwilson.net", Dylanwilson.net, 2016. [Online]. Available: http://www.dylanwilson.net/dissection-of-the-single-responsibility-principle. [Accessed: 27- Nov- 2016].
[4]"About Mojio, the Open Connected Car Platform", Mojio, 2016. [Online]. Available: https://www.moj.io/our-company. [Accessed: 27- Nov- 2016].
[5]J. Greenough, "How the 'Internet of Things' will impact consumers, businesses, and governments in 2016 and beyond", Business Insider, 2016. [Online]. Available: http://www.businessinsider.com/how-the-internet-of-things-market-will-grow-2014-10. [Accessed: 27- Nov- 2016].

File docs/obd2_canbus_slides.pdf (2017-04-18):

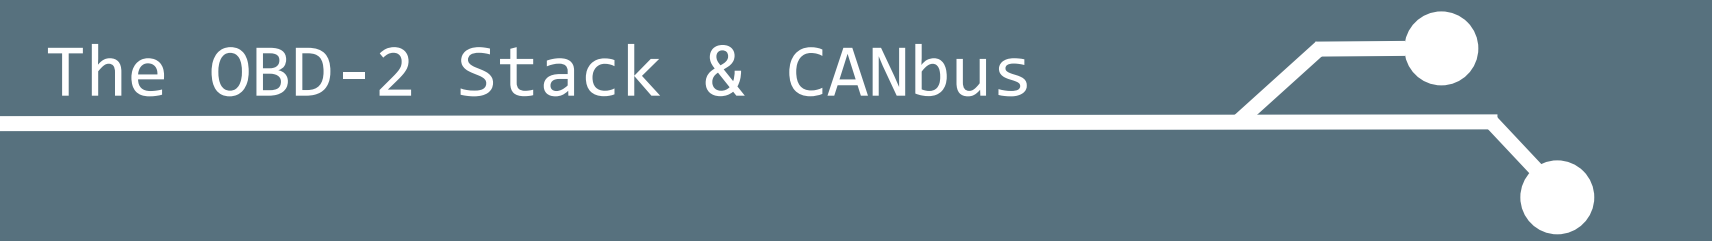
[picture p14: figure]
The OBD-2 Stack & CANbus

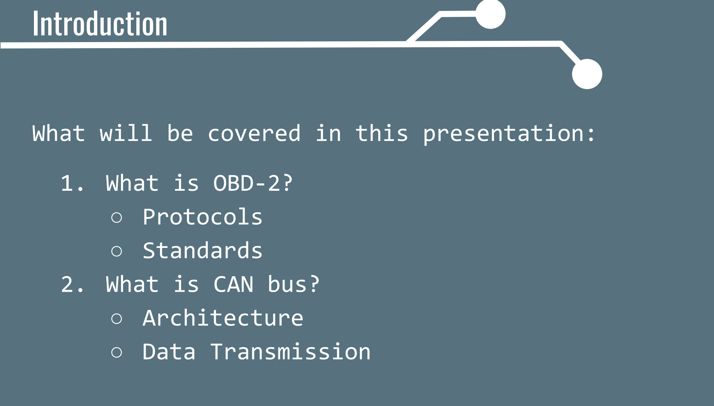
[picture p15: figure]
Introduction; 1. What is OBD-2? ○ Protocols ○ Standards 2. What is CAN bus? ○ Architecture ○ Data Transmission

## What will be covered in this presentation:

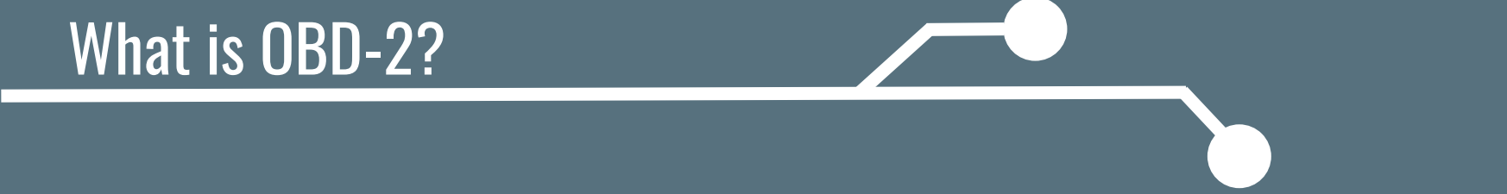
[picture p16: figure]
What is OBD-2?

## OBD-2 is the latest iteration of a standard for

vehicle self-diagnostic and reporting.

OBD-2 includes many standards (SAE, ISO) that specify the different technical components that make up a self-diagnostic & reporting system.

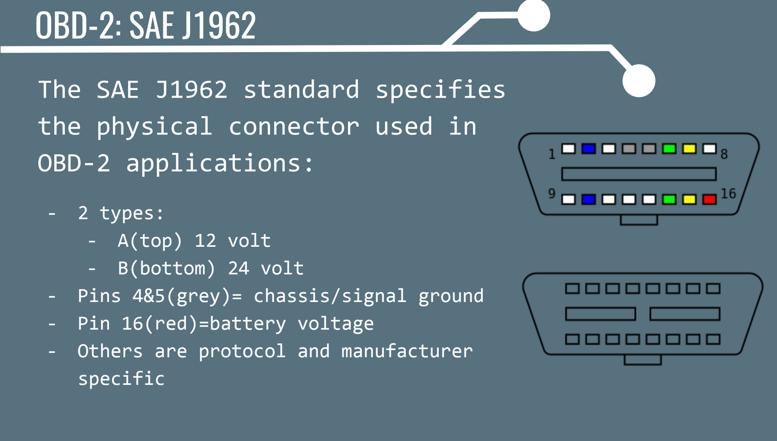
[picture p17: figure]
OBD-2: SAE J1962; The SAE J1962 standard specifies the physical connector used in OBD-2 applications:; - 2 types: - A(top) 12 volt - B(bottom) 24 volt - Pins 4&5(grey)= chassis/signal ground - Pin 16(red)=battery voltage - Others are protocol and manufacturer specific

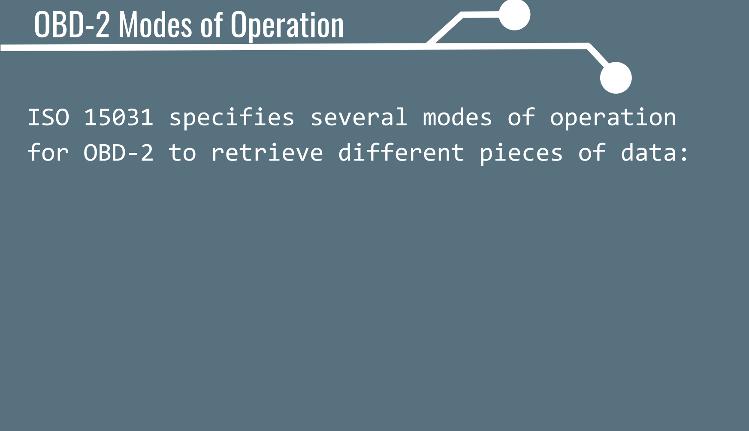
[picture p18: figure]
OBD-2 Modes of Operation

## ISO 15031 specifies several modes of operation for OBD-2 to retrieve different pieces of data:

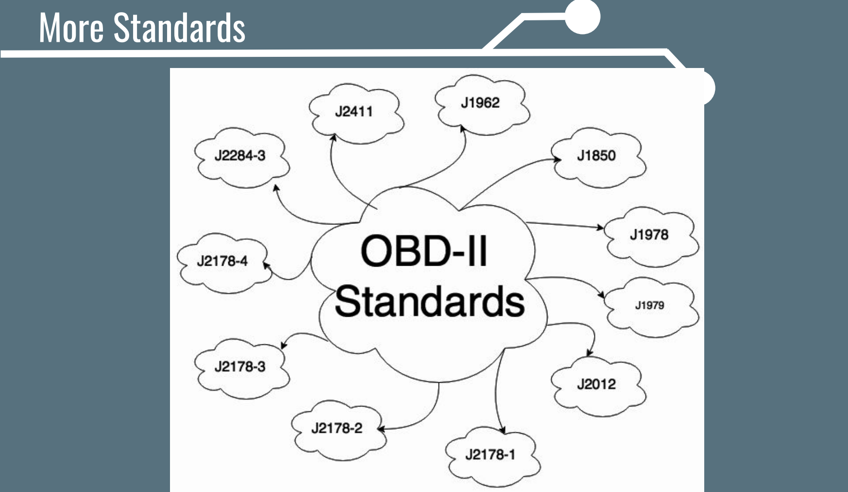
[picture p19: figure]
More Standards

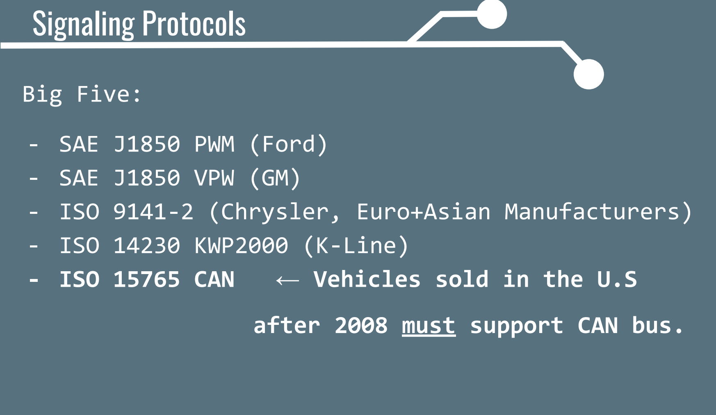
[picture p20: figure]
Signaling Protocols; Big Five:; - SAE J1850 PWM (Ford) - SAE J1850 VPW (GM); - ISO 14230 KWP2000 (K-Line); after 2008 must support CAN bus.

## - ISO 9141-2 (Chrysler, Euro+Asian Manufacturers)

## - ISO 15765 CAN ← Vehicles sold in the U.S

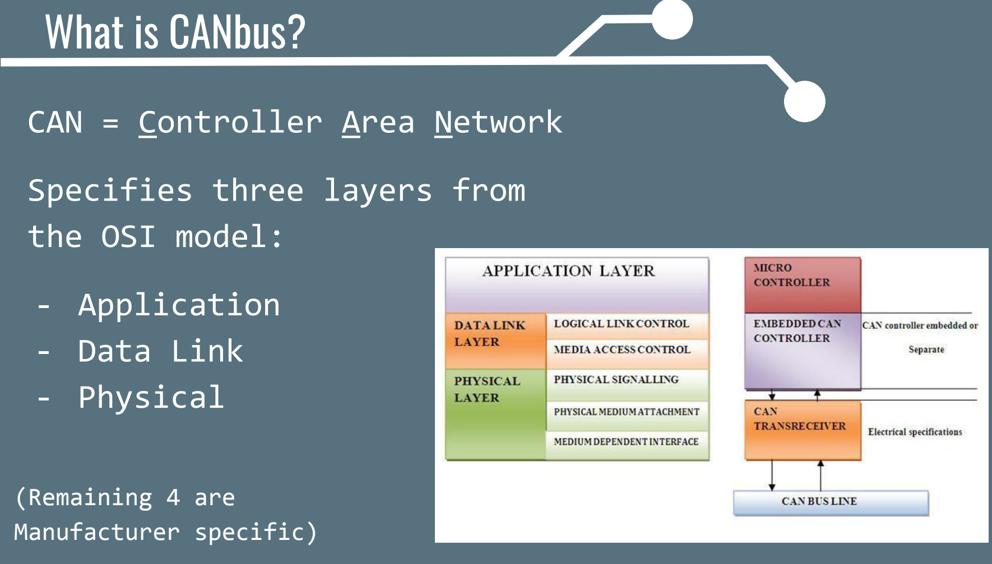
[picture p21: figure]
What is CANbus?; CAN = Controller Area Network; Specifies three layers from the OSI model:; - Application - Data Link - Physical; (Remaining 4 are Manufacturer specific)

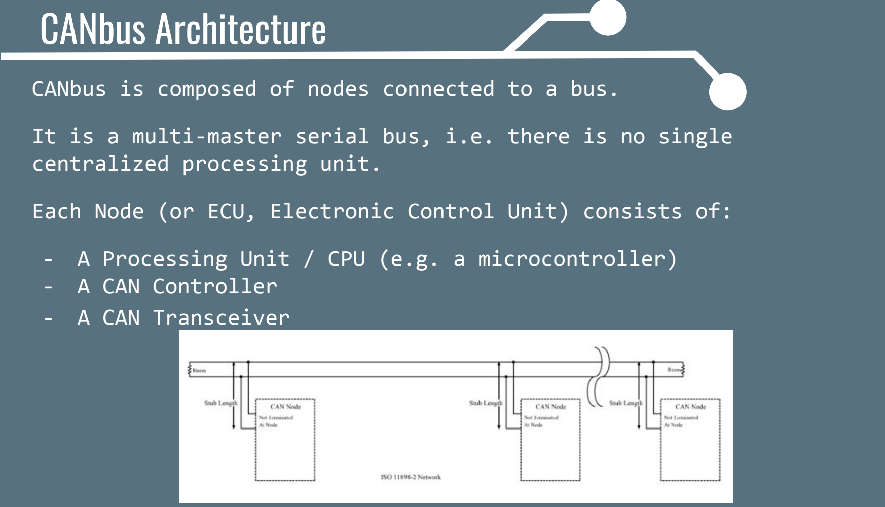
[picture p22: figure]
CANbus Architecture; centralized processing unit.; - A CAN Controller - A CAN Transceiver

CANbus is composed of nodes connected to a bus.

It is a multi-master serial bus, i.e. there is no single

Each Node (or ECU, Electronic Control Unit) consists of:

- A Processing Unit / CPU (e.g. a microcontroller)

# CANBus: Data Transmission

CAN uses something called a lossless, bitwise arbitration system:

- The nodes are synchronized to read bits at the same time, but data transmission is not regulated by a clock.
- There are “Dominant” bits and “Recessive” bits
- If one node transmits a “Dominant” bit, and another one transmits “Recessive”, the dominant node wins.
- For example, Brake system always has “Dominant” bit
- Additionally, the lower a Node’s ID number, the higher its priority.

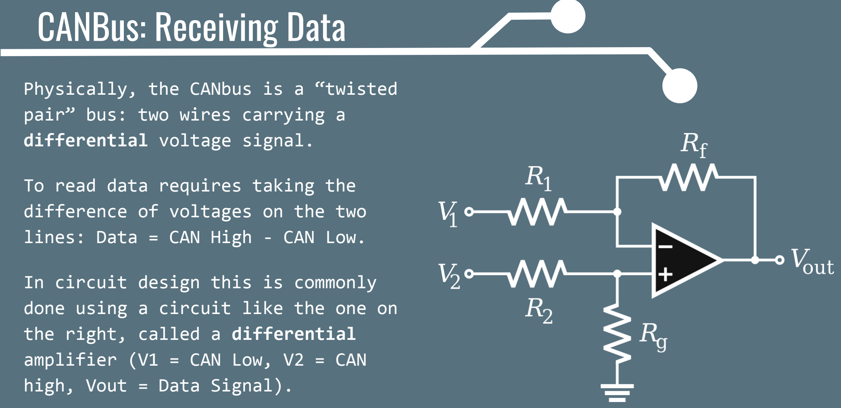
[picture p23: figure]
CANBus: Receiving Data; Physically, the CANbus is a “twisted pair” bus: two wires carrying a differential voltage signal.; To read data requires taking the difference of voltages on the two lines: Data = CAN High - CAN Low.; In circuit design this is commonly done using a circuit like the one on the right, called a differential amplifier (V1 = CAN Low, V2 = CAN high, Vout = Data Signal).

Note: All of the resistors (squiggly lines) will be of equal value. This is to create a “unity gain”. If the values are not equal, the circuit will have an output gain, meaning the signal will be amplified by some value. This is undesirable because it could cause large voltages that may overload the controller.

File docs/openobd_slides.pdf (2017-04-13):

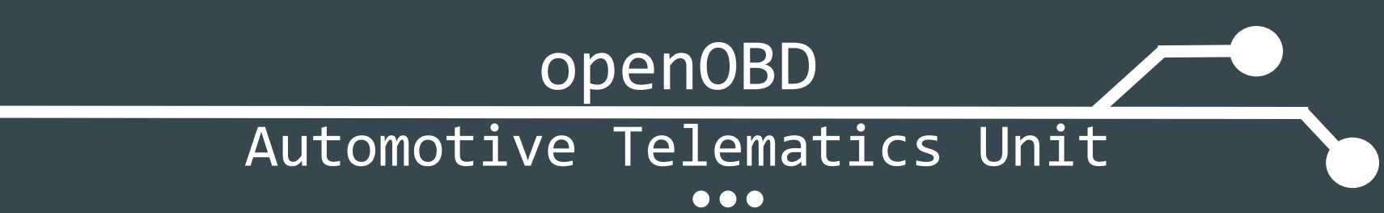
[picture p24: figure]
openOBD Automotive Telematics Unit

### Nicholas Mulvenna Kaibo Ma Ehsan Ahmadi Isaiah Thiessen

# Project Goal

# - Vehicle data acquisition through OBD-2 port - Open source platform - Easy integration of new hardware & software - Modular software & hardware design - More control over functions & features - More customizable data from devices

# What is OBD-2?

### OBD-2 is a standard for vehicle

self-diagnostic and reporting.

### (mandatory in U.S. since 1996)

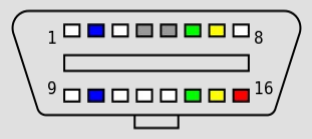
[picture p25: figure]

### It provides real time data communication in addition to a set of diagnostic trouble

codes called PIDs (Parameterized IDs).

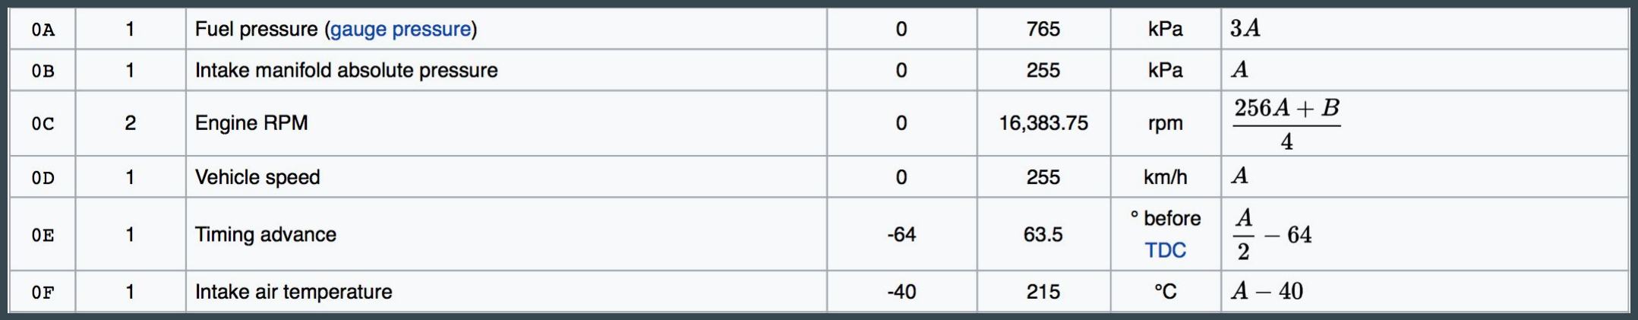
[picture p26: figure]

# What is CAN Bus?

CAN =

Controller

Area

Network


(found in most N. American cars ~2001 onward)

CANbus is composed of nodes connected to a bus.

It is a multi-master serial bus, i.e. there is no single centralized processing unit.

Each Node (or ECU, Electronic Control Unit) consists of: - A Processing Unit / CPU (e.g. a

microcontroller)
- A CAN Controller - A CAN Transceiver


# High-Level Design

CPU: | Raspberry Pi Zero Communicates with all hardware
Power: | Wide input switching buck converter Provides power from OBD Ignition on/off detection for low power mode
CAN: | Controller implements CAN protocol Transceiver translates signals to and from bus
Sensors: | GPS+GSM module provides GPS data and network connectivity; IMU provides accel, gyro, temperature, ADC for battery voltage
Code: | Python Scripts read inputs, Object/Interface-oriented framework

# Hardware Design Choices

### Raspberry Pi Zero: Great online community Plenty of processing power for a small cost GPIO for hardware interface

### Power Supply: Reduces energy consumption. Less heat dissipated High Frequency, small footprint, wide input range

CAN: | Linux drivers + open source libraries available for controller

### Simple interfacing over SPI, 3.3V compatible

Sensors: | Simple interfacing over I2C (IMU module), Open Source libraries
Network/GPS: | SIM808 module combines 2 features; open
documentation & simple implementation; smaller footprint | 6

# PCB (rev 1.0)


High density compact design.

Only 3mm wider than
Raspberry pi 0 footprint.

External antenna connections.

Sim card holder and ignition detection for low power mode

BOTTOM

TOP

# Software Design - Overview


# Software Design - Devices


# Software Testing - Example using a Mock Class


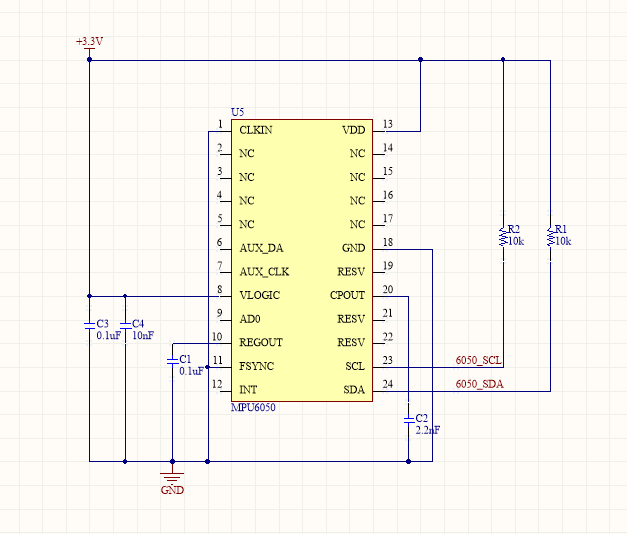
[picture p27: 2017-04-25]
hardware/images/mpu6050_sch.png

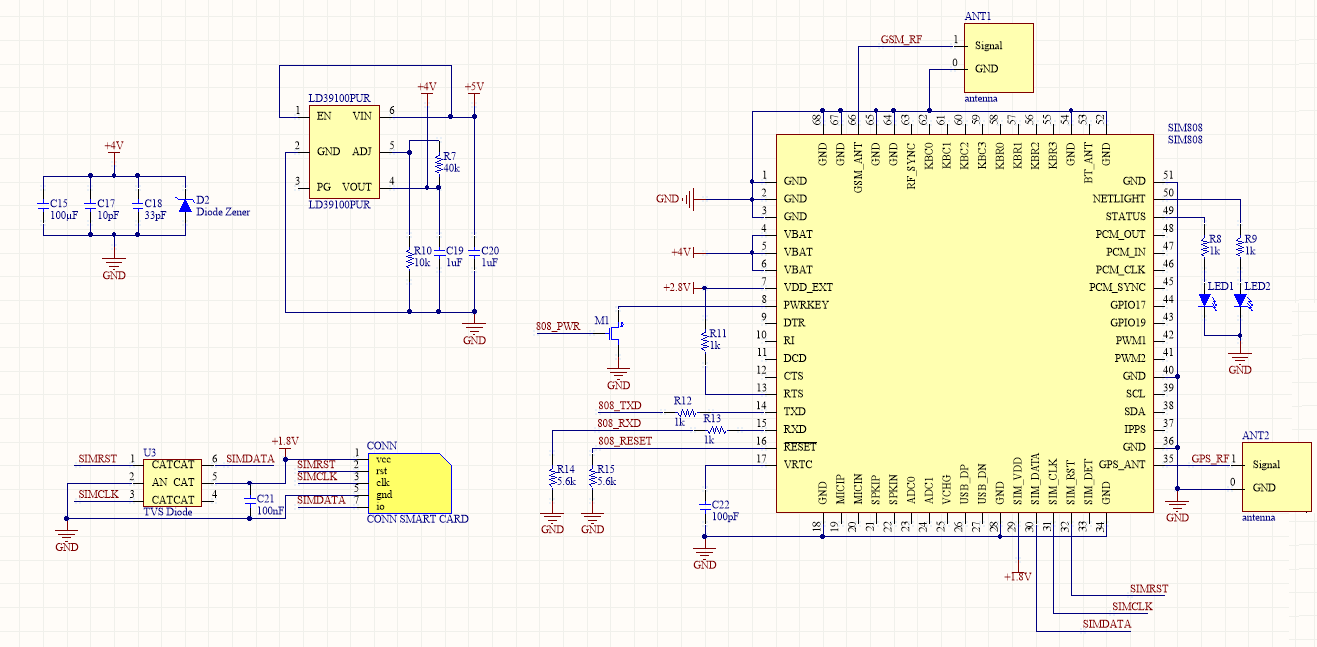
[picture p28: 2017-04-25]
hardware/images/sim808_sch.png

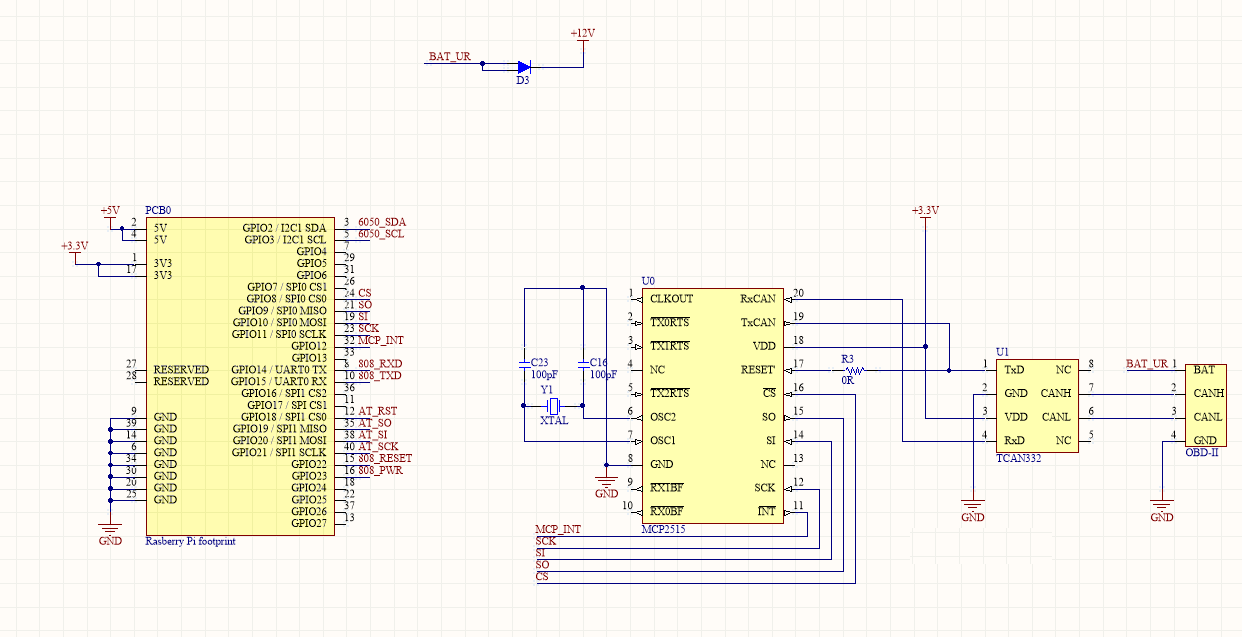
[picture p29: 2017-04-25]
hardware/images/can_node_sch.png

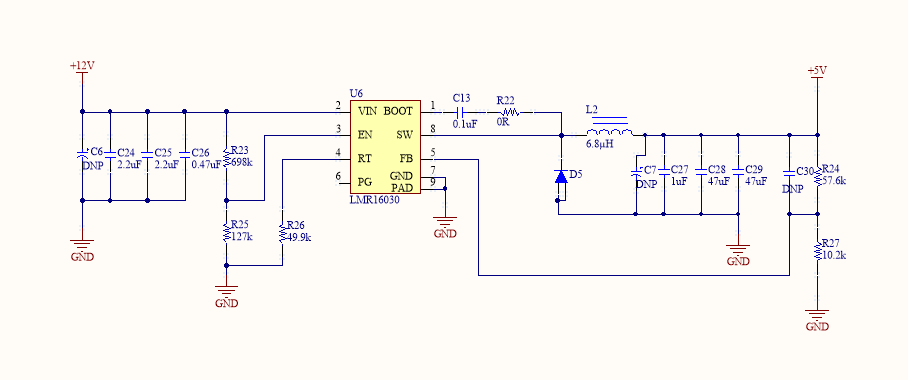
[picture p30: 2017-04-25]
hardware/images/power_circuit_sch.png

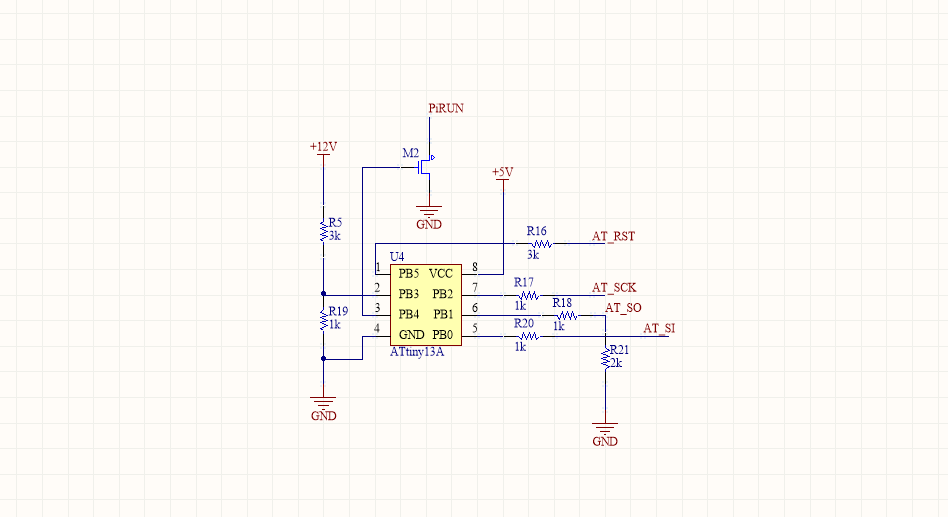
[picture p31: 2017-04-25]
hardware/images/atiny_sch.png

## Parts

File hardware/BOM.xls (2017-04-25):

Digi-Key Part Number | Manufacturer | Manufacturer Part Number | Description
SS5P6-M3/86AGICT-ND | VISHAY SEMICONDUCTOR DIODES DIVISION (VA) | SS5P6-M3/86A | DIODE SCHOTTKY 60V 5A TO277A
535-9840-1-ND | ABRACON LLC (VA) | ABM7-16.000MHZ-D2Y-T | CRYSTAL 16.0000MHZ 18PF SMD
MCP2515T-I/MLCT-ND | MICROCHIP TECHNOLOGY (VA) | MCP2515T-I/ML | IC CAN CTLR W/SPI 2.0B 20-QFN
296-43711-1-ND | TEXAS INSTRUMENTS (VA) | TCAN332DR | IC TXRX CAN 3.3V 8SOIC
1428-1007-1-ND | INVENSENSE (VA) | MPU-6050 | IMU ACCEL/GYRO 3-AXIS I2C 24QFN
MMSZ5231BT1GOSCT-ND | ON SEMICONDUCTOR (VA) | MMSZ5231BT1G | DIODE ZENER 5.1V 500MW SOD123
497-11013-1-ND | STMICROELECTRONICS (VA) | LD39100PUR | IC REG LDO ADJ 1A 6DFN
SMF05CT2GOSCT-ND | ON SEMICONDUCTOR (VA) | SMF05CT2G | TVS DIODE 5VWM 12.5VC SOT363
732-5957-1-ND | WURTH ELECTRONICS INC (VA) | 693022010811 | CONN SMART CARD
1727-4924-1-ND | NEXPERIA USA INC (VA) | BSH105,215 | MOSFET N-CH 20V 1.05A SOT23
160-1179-1-ND | LITE-ON INC (VA) | LTST-C170GKT | LED GREEN CLEAR 0805 SMD
160-1422-1-ND | LITE-ON INC (VA) | LTST-C171EKT | LED RED CLEAR 0805 SMD
ATTINY13A-SSU-ND | MICROCHIP TECHNOLOGY | ATTINY13A-SSU | IC MCU 8BIT 1KB FLASH 8SOIC
296-44513-5-ND | TEXAS INSTRUMENTS | LMR16030PDDA | IC REG BUCK ADJ 3A 8SOPWRPD
490-3385-1-ND | MURATA ELECTRONICS (VA) | GRM32ER72A225KA35L | CAP CER 2.2UF 100V X7R 1210
490-3326-1-ND | MURATA ELECTRONICS (VA) | GRM21BR72A474KA73L | CAP CER 0.47UF 100V X7R 0805
541-698KHCT-ND | VISHAY DALE (VA) | CRCW0603698KFKEA | RES SMD 698K OHM 1% 1/10W 0603
541-127KHCT-ND | VISHAY DALE (VA) | CRCW0603127KFKEA | RES SMD 127K OHM 1% 1/10W 0603
541-49.9KHCT-ND | VISHAY DALE (VA) | CRCW060349K9FKEA | RES SMD 49.9K OHM 1% 1/10W 0603
490-1532-1-ND | MURATA ELECTRONICS (VA) | GRM188R71C104KA01D | CAP CER 0.1UF 16V X7R 0603
541-0.0GCT-ND | VISHAY DALE (VA) | CRCW06030000Z0EA | RES SMD 0.0OHM JUMPER 1/10W 0603
732-4108-1-ND | WURTH ELECTRONICS INC (VA) | 7447714068 | FIXED IND 6.8UH 5.2A 22 MOHM SMD
490-6484-1-ND | MURATA ELECTRONICS (VA) | GRM21BR71E105KA99L | CAP CER 1UF 25V X7R 0805
490-3888-1-ND | MURATA ELECTRONICS (VA) | GRM32ER61C476ME15L | CAP CER 47UF 16V X5R 1210
541-57.6KHCT-ND | VISHAY DALE (VA) | CRCW060357K6FKEA | RES SMD 57.6K OHM 1% 1/10W 0603
541-10.2KHCT-ND | VISHAY DALE (VA) | CRCW060310K2FKEA | RES SMD 10.2K OHM 1% 1/10W 0603
WM3476-ND | MOLEX, LLC | 0685031602 | OBD MALE HOUSING 16POS
WM3455CT-ND | MOLEX, LLC (VA) | 0579649702 | .060 MALE TERM
H122041-ND | HIROSE ELECTRIC CO LTD | U.FL-R-SMT-1(01) | CONN UMC RCPT STR 50 OHM SMD
553-2585-ND | PULSE ELECTRONICS CORPORATION | W3538B0150 | ANTENNA PENTA BAND 150MM U.FL
S9200-ND | SULLINS CONNECTOR SOLUTIONS | SFH11-PBPC-D20-ST-BK | CONN HEADR FMALE 40POS .1" DL AU

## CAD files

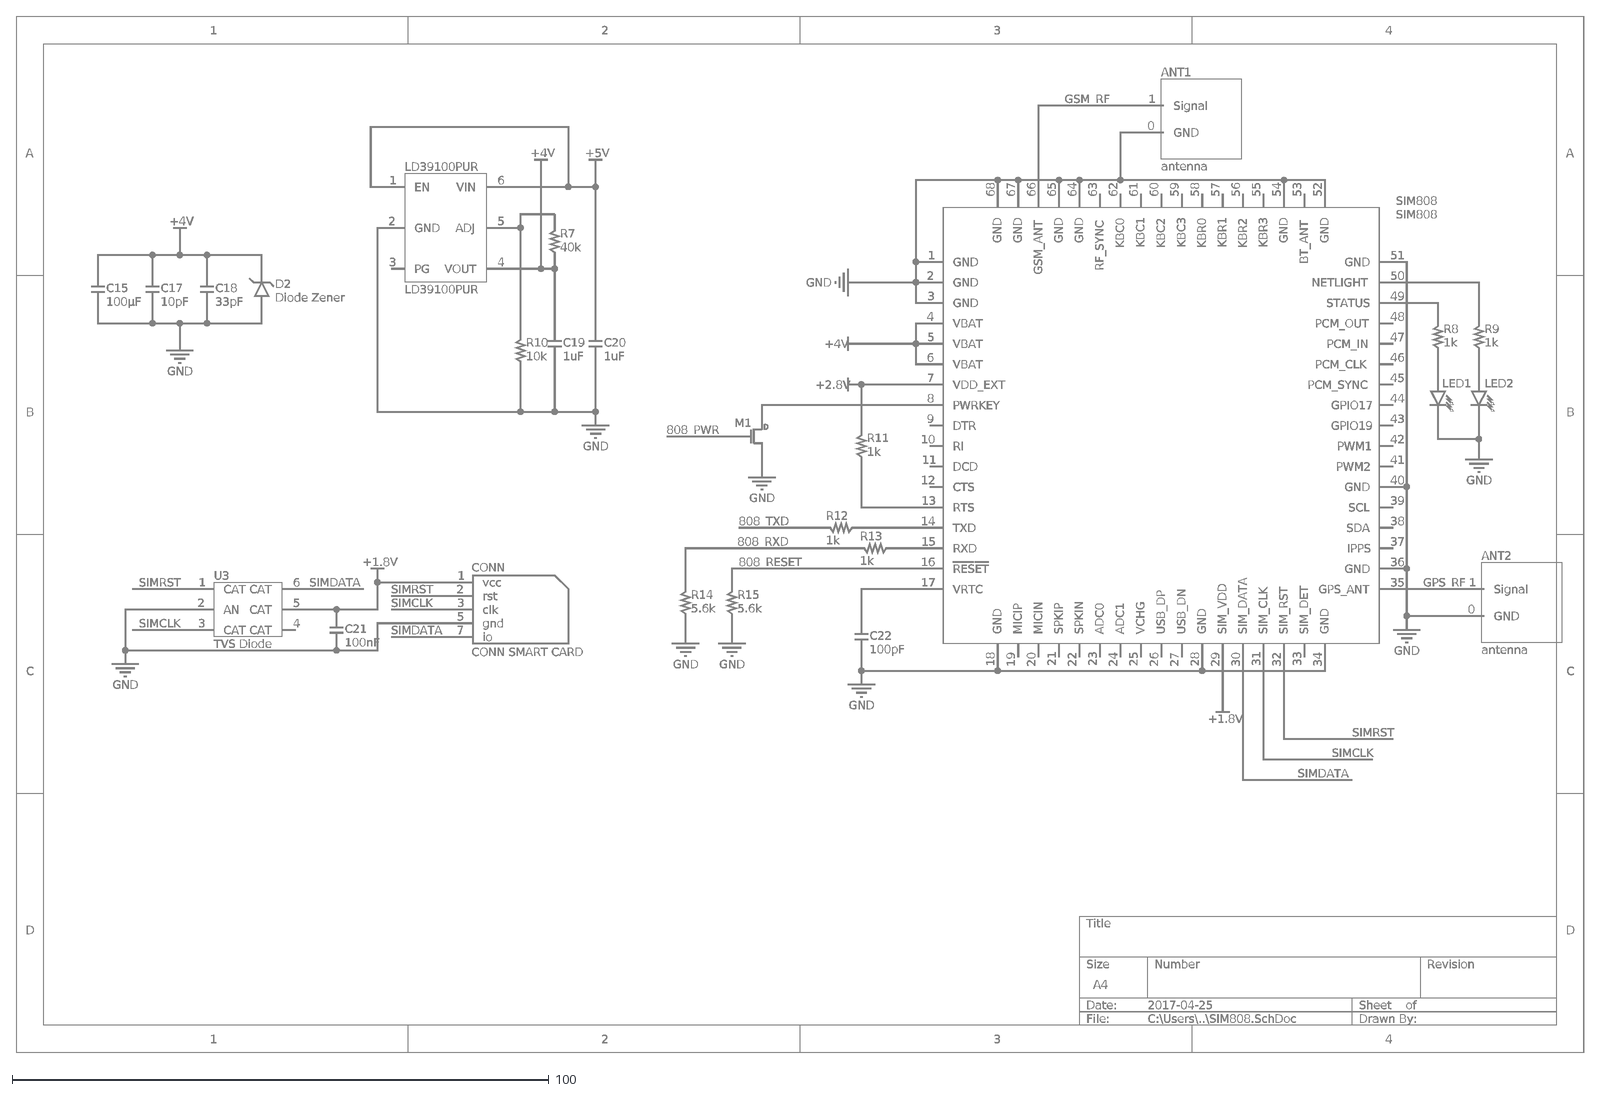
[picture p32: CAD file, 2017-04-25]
hardware/SIM808.dxf
1
2
3
4
D
C
B
A
Title
Number
Revision
Size
A4
Date:
2017-04-25
Sheet of
File:
C:\Users\..\SIM808.SchDoc
Drawn By:
GND
VBAT
5
6
VDD_EXT
7
PWRKEY
8
DTR
9
RI
10
DCD
11
CTS
12
RTS
13
TXD
14
RXD
15
RESET
16
VRTC
17
18
MICIP
19
MICIN
20
SPKIP
21
SPKIN
22
ADC0
23
ADC1
24
VCHG
25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

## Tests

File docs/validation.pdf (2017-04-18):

# openOBD

# Automotive Telematics Unit

# Validation - v3.1

## Authors:

## - Nicholas Mulvenna

## - Kaibo Ma

## - Ehsan Ahmadi

## - Isaiah Thiessen

Table of Contents

History of Revisions | 2
List of Figures | 3
List of Technical Terms | 3
1 - Introduction | 3
2 - Actions Taken Toward Product Validation | 4
2.1 - Manual Tests | .
2.2 - Automated Tests | 5
3 - References | 6

History of Revisions

Version | Authors | Date | Changes
1 | Isaiah Thiessen Kaibo Ma Nicholas Mulvenna Ehsan Ahmadi | 2016-11-28 | Initial Draft
2 | Kaibo Ma | 2017-02-13 | Added OBD2 Validation for Simulation Testing and Actual Testing
3 | Isaiah Thiessen Nicholas Mulvenna | 2017-04-05 | Removed plan to test heat output and power consumption
3.1 | Nicholas Mulvenna | 2017-04-17 | Wording

List of Figures

Figure 1.0: Testing Cycle | 5
Figure 2.0: Testing Using Mocks | 5

List of Technical Terms

Term | Definition
Regression Testing | Regression testing is a type of software testing that verifies that software previously developed and tested still performs correctly even after it was changed or interfaced with other software.
Smoke Testing | Also known as “Build Verification Testing”, smoke testing is a type of software testing that comprises of a non-exhaustive set of tests that aim at ensuring that the most important functions work.
Unit Testing | Usually run by developers to test each function as a single entity. Tested against input and output.
Integration Testing | Run by developers to test newly created functionality once put into the rest of the system. Usually tested against specifications.
System Testing | Also known as Regression Testing, where developer or Quality Assurance Engineers test the whole system with newly added features. Usually tested against requirements.

User Acceptance
Testing

Usually last step in testing cycle where the system as a whole is verified and validated to meet all client needs.

1 - Introduction
This document states the validation plan for the Automotive Telematics Unit. It will go over the techniques and methodologies in testing and ensuring quality control and safety for end users.

2 - Actions Taken Toward Product Validation
2.1 - Manual Tests
Approach:
- Manual testing is done using a terminal interface for FS03. We run basic user tests for functions like getting sensor readings from:
- GPS
- OBD2
- Temperature
- Accelerometer
- Gyroscope

We run Smoke Tests against the command line interface. Essentially we try to emulate what an end user may want to perform with our product. All features are tested against multiple trials to make sure there are no anomalies. It is important to cover all major feature of the application so that we can ensure the quality of the program.
- Manual measurements using lab tools for FS07
- Oscilloscope to check CAN bus transmission is stable
- Multimeter to ensure level converters are stepping up and down correctly
- OBD2: There were two stages for OBD2 testing and debugging for FS01.

- Stage One: Was to test our software and hardware against an OBD2 CAN bus simulator that was custom written over an arduino. We connected our Pi and hardware to an arduino running software that simulated a CAN bus network of a vehicle. Our Pi would read the data from Arduino much like how we would read from the OBD2 port of an actual vehicle. Our Pi would either listen over the simulated CAN bus or send queries over the CAN bus to the arduino to get responses and data. For example, we would send requests to the virtual engine to request rpms. This method allowed us to be able to test our software and hardware without the need to be in a vehicle. It will allow us to transfer the data and knowledge of testing with the simulator to that of testing with an actual vehicle.
- Stage 2: We test against the OBD2 Port of the car. We take the knowledge and confidence that we obtained with testing against a simulator to test with an actual OBD2 network. We connected our device to listen to the CAN bus network of the OBD2 port of a 2015 Toyota Camry. We were able to obtain data transmissions from the car as well as the ability to send the network queries for rpm, speed, and fuel levels. The car would respond instantaneously with what data we queried. From testing on Stage 2 with the car, we can now validate FS01.

2.2 - Automated Tests
Approach:
- We perform automated software tests using the pytest library. We begin at client needs and determine our requirements for the project. The development team then designs and implements the code as well as its unit tests. If they pass, the newly written code is integrated into the system to see if it also performs according to the design. Then once that passes, the whole system is tested against the requirements, also known as regression testing. Finally, our user acceptance tests (using client needs as a rubric) must pass.

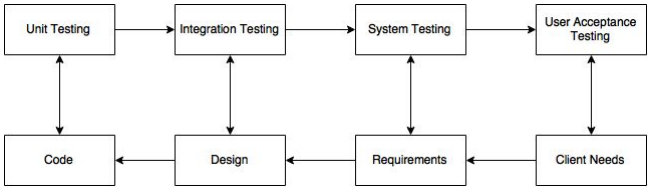
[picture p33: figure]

Figure 1.0: Testing Cycle

- During development, mocks are used in place of classes that directly interact with hardware in some tests to fulfill requirement NS04.

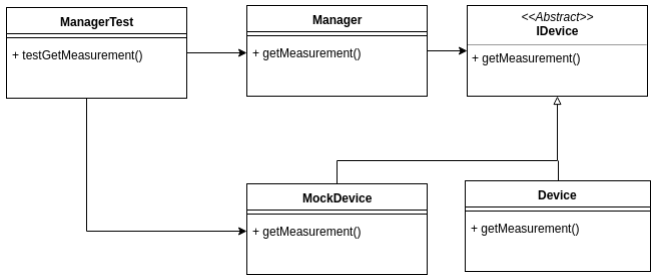
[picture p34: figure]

Figure 2.0 Testing Using Mocks

- Figure 2.0 demonstrates the use of mocks when testing classes that do not directly depend on hardware devices (such as sensors or the GPS module). [1] [2] [3] In this example, suppose that a Manager class depends on an abstract IDevice class. When running the application, a concrete Device class is used. However, a concrete MockDevice class can imitate the physical hardware’s behaviour so ManagerTest can run without it.
- Hardware tests were performed using short test scripts to test that sensors read correctly and consistently, in order to validate that FS02 is fulfilled. These scripts are written explicitly for each separate device. Tests performed to-date for all sensors have been successful.

- A CAN bus simulator was used to generate random data on a bus, which was read using the current prototype to verify that data was being read correctly, per FS01. This test was successful and will continue to be used as a test method for future iterations.
- Test points are included on the PCB in order to verify that the
hardware is functioning correctly.

3 - References
[1]"Progress Before Hardware", Wingman Software, 2004. [Online]. Available: https://wingman-sw.com/papers/ProgressBeforeHardware.pdf. [Accessed: 27- Nov-2016].
[2]A. Jordan Schaenzle, "The mock object approach to test-driven development", Embedded, 2016. [Online]. Available: http://www.embedded.com/design/prototyping-and-development/4398723/The-mock-object-approach-to-test-driven-development. [Accessed: 27- Nov- 2016].
[3]"For embedded TDD, don't worry so much about testing on the target", ElectronVector - Test-First Embedded Software, 2016. [Online]. Available: http://www.electronvector.com/blog/for-embedded-tdd-dont-worry-so-much-about-tes ting-on-the-target. [Accessed: 27- Nov- 2016].
[4] Kolawa, Adam; Huizinga, Dorota (2007). Automated Defect Prevention: Best Practices in Software Management. (http://www.wiley.com/WileyCDA/WileyTitle/productCd-0470042125.html) Wiley-IEEE Computer Society Press. pp. 41–43. ISBN (https://en.wikipedia.org/wiki/International_Standard_Book_Number) 0-470-04212-5. (https://en.wikipedia.org/wiki/Special:BookSources/0-470-04212-5)
[5] "Smoke Testing." Software Testing Fundamentals. N.p., n.d. Web. 28 Nov. 2016. <http://softwaretestingfundamentals.com/smoke-testing/>.
[6] @whatisdotcom. "What Is Regression Testing? - Definition from WhatIs.com." SearchSoftwareQuality. N.p., n.d. Web. 28 Nov. 2016. <http://searchsoftwarequality.techtarget.com/definition/regression-testing>.

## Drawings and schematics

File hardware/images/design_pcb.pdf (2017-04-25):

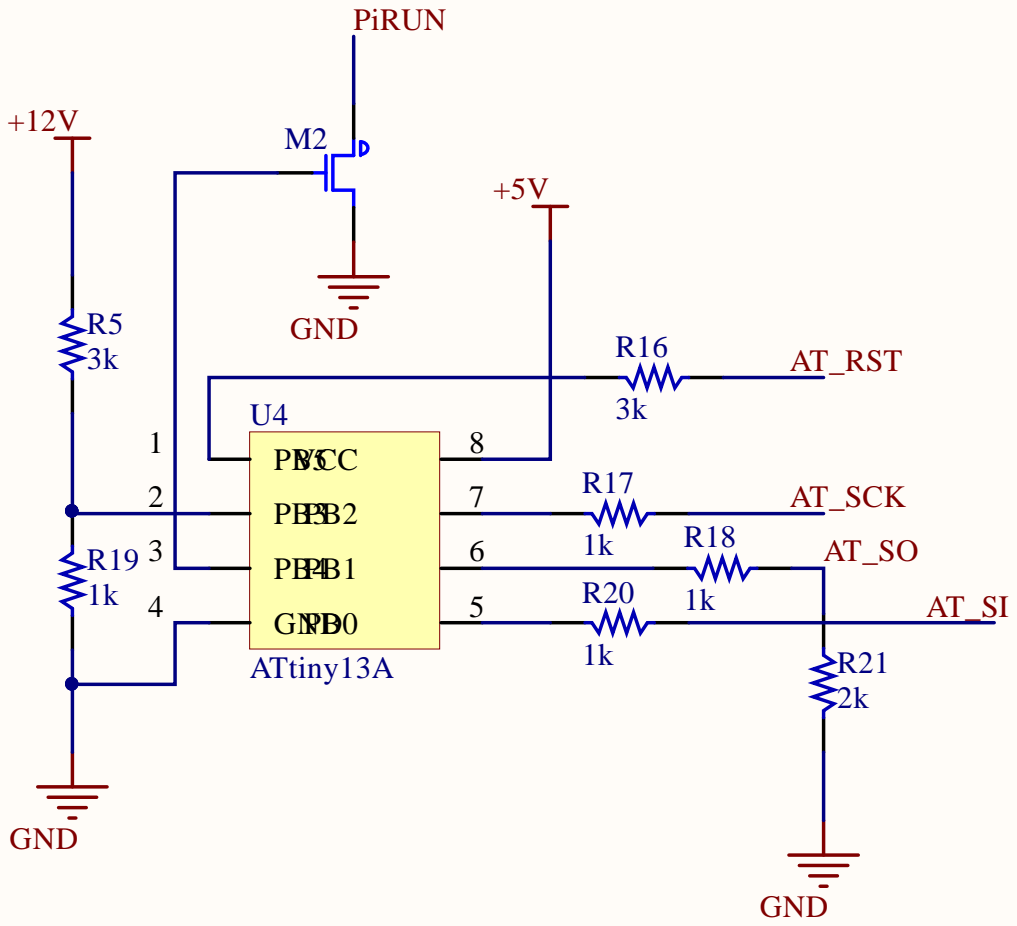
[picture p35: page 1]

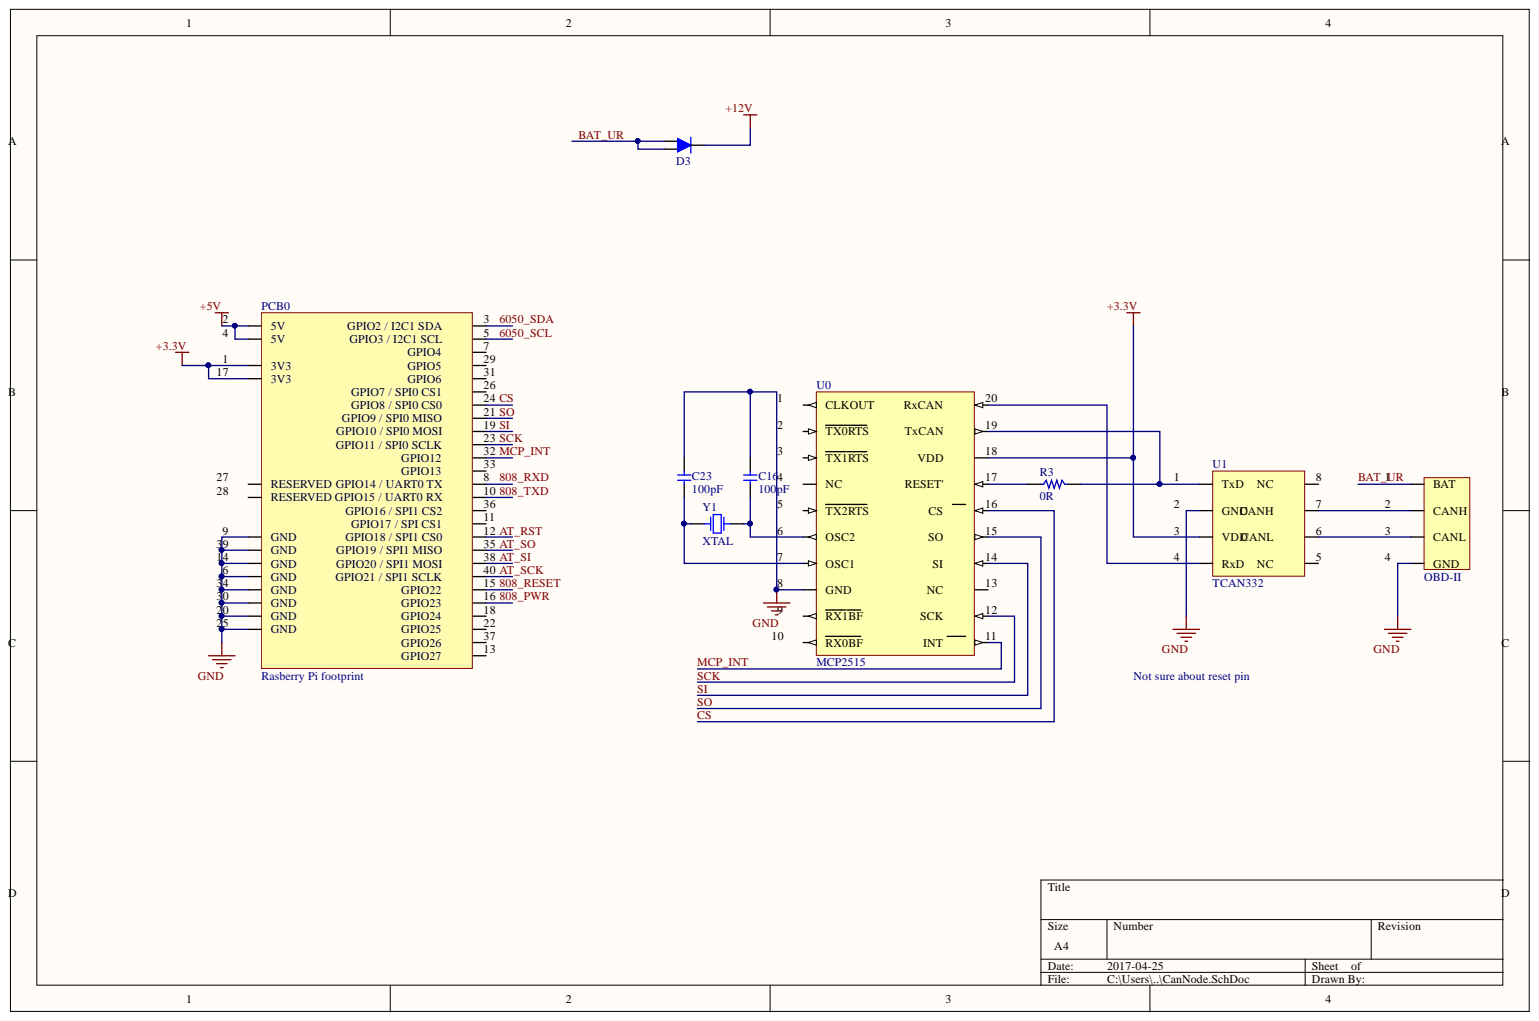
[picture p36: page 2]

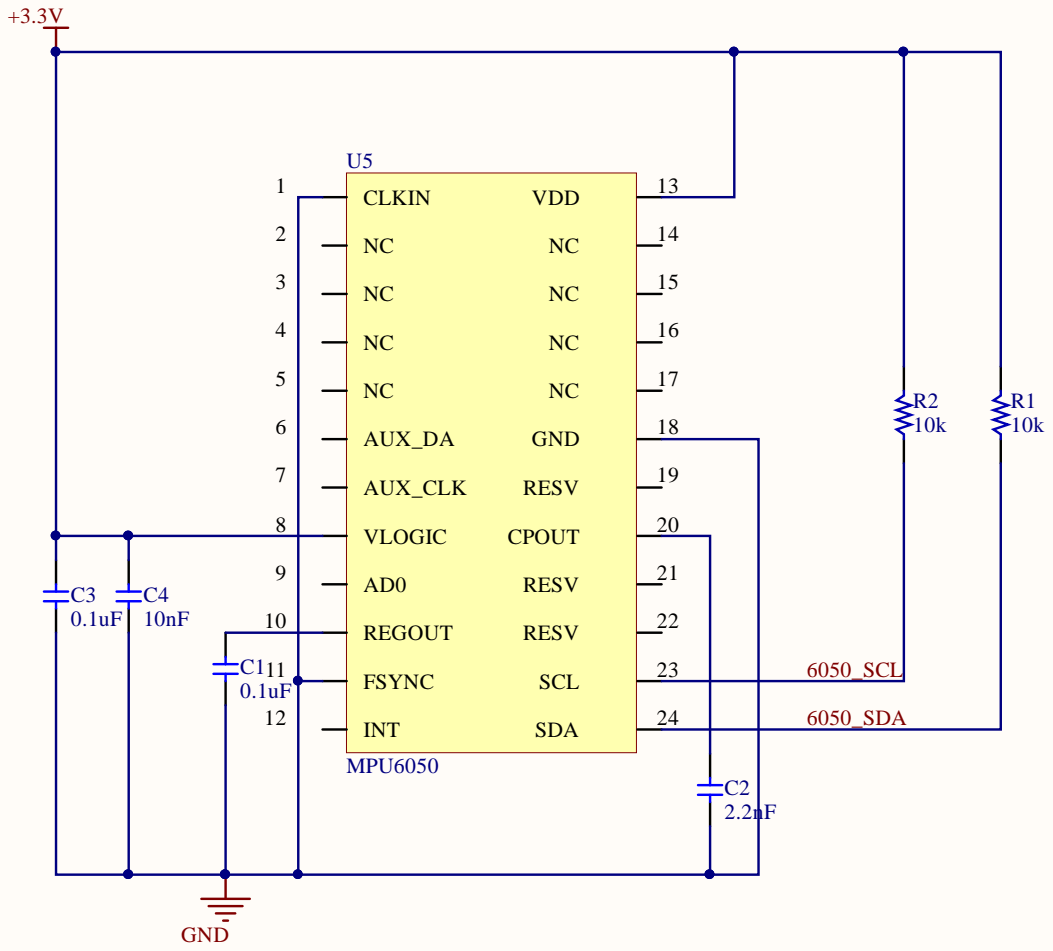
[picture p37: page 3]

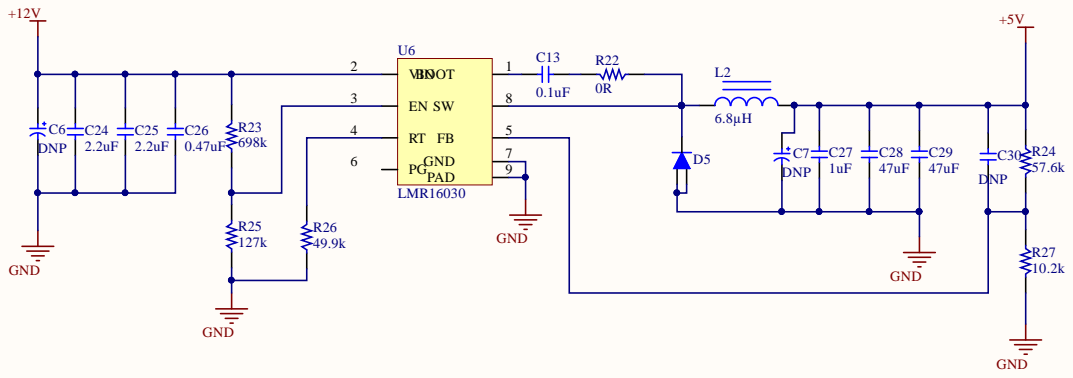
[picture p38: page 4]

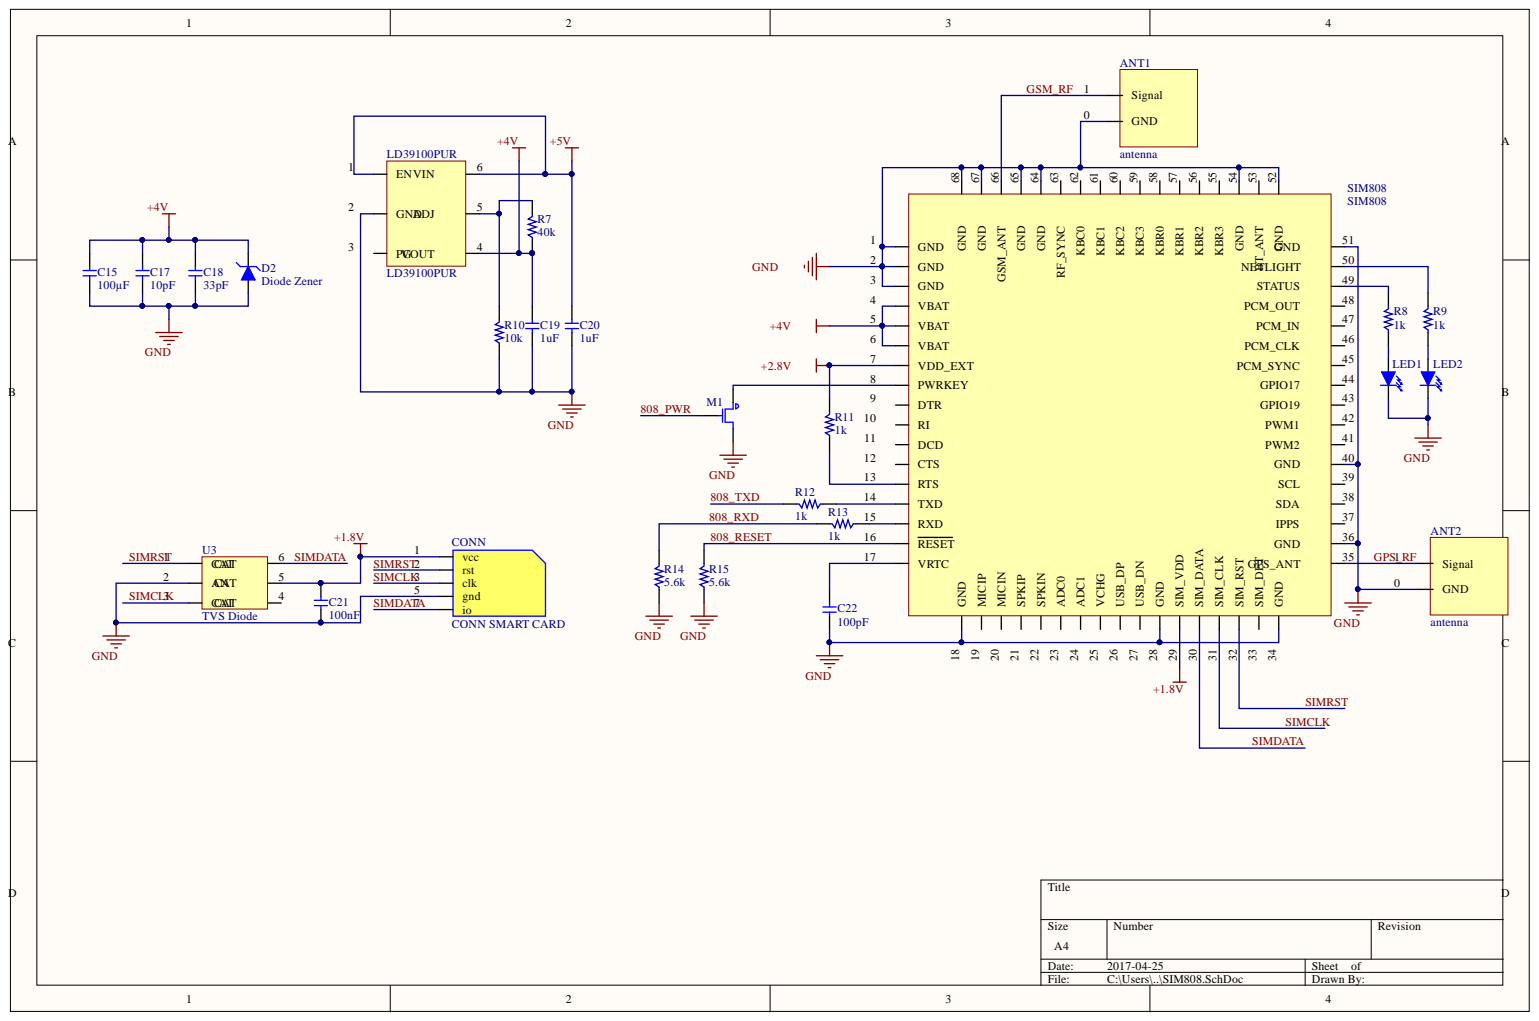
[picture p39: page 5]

5 0
4 9

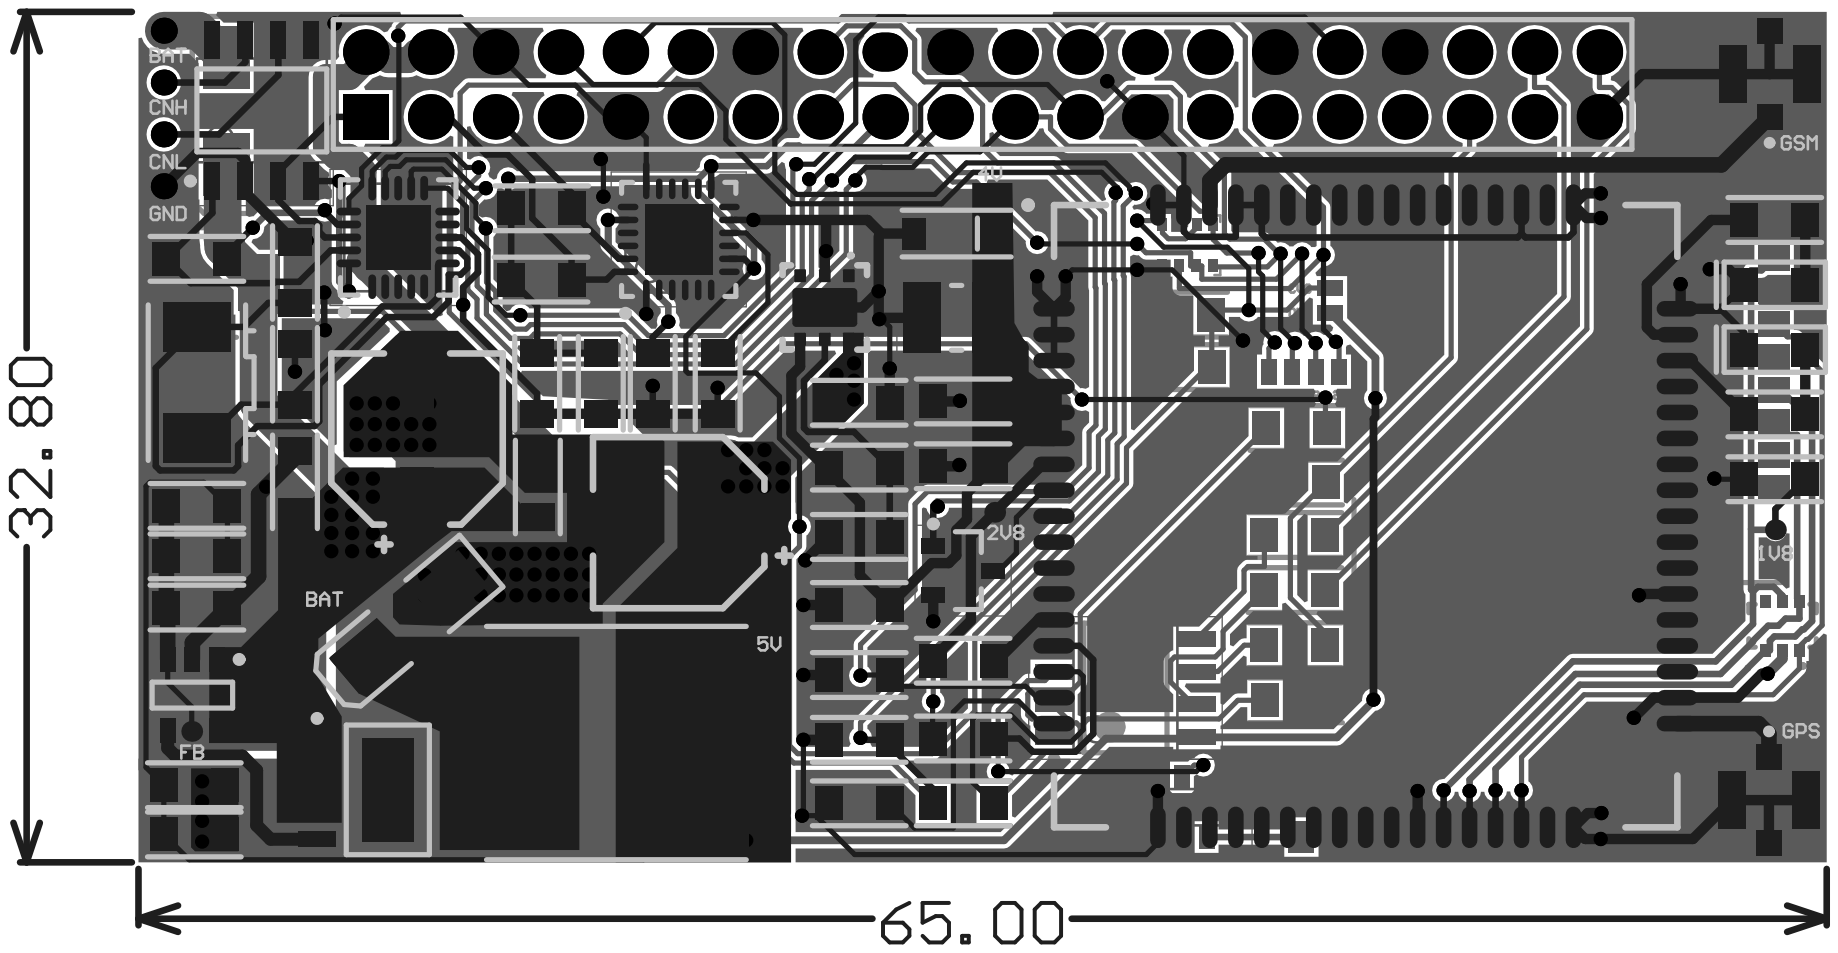
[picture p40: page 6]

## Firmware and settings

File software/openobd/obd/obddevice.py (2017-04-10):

from obd.iobddevice import IOBDDevice
from measure.measure import Measure
import time
import can
import os
import datetime

class OBDDevice(IOBDDevice):
	"""OBD Device that can send PIDs and read from the CAN bus"""

	def __init__(self):
		self._ready = False
		self.bus = None
		self.canlistener = None

	def initialize(self):
		os.system('sudo ip link set can0 type can bitrate 125000 triple-sampling on')
		os.system('sudo ifconfig can0 up')
		can.rc['interface'] = 'socketcan_native'
		self.bus = can.interface.Bus('can0')
		self._ready = True
	
	@property
	def ready(self) -> bool:
		return self._ready

	def init_pids(self, mode):
		PID_dict = {}
		PID_dict['pidsupport'] = [0x02, mode, 0x00, 0x00, 0x00, 0x00, 0x00, 0x00]
		PID_dict['monitor_status'] = [0x02, mode, 0x01, 0x00, 0x00, 0x00, 0x00, 0x00]
		PID_dict['freeze_dtc'] = [0x02, mode, 0x02, 0x00, 0x00, 0x00, 0x00, 0x00]
		PID_dict['fuel_system_status'] = [0x02, mode, 0x03, 0x00, 0x00, 0x00, 0x00, 0x00]
		PID_dict['engine_load'] = [0x02, mode, 0x04, 0x00, 0x00, 0x00, 0x00, 0x00]
		PID_dict['coolant_temp'] = [0x02, mode, 0x05, 0x00, 0x00, 0x00, 0x00, 0x00]
		PID_dict['sterm_fuel1'] = [0x02, mode, 0x06, 0x00, 0x00, 0x00, 0x00, 0x00]
		PID_dict['lterm_fuel1'] = [0x02, mode, 0x07, 0x00, 0x00, 0x00, 0x00, 0x00]
		PID_dict['sterm_fuel2'] = [0x02, mode, 0x08, 0x00, 0x00, 0x00, 0x00, 0x00]
		PID_dict['lterm_fuel2'] = [0x02, mode, 0x09, 0x00, 0x00, 0x00, 0x00, 0x00]
		PID_dict['fuel_pressure'] = [0x02, mode, 0x0A, 0x00, 0x00, 0x00, 0x00, 0x00]
		PID_dict['intake_manifold_pressure'] = [0x02, mode, 0x0B, 0x00, 0x00, 0x00, 0x00, 0x00]
		PID_dict['rpm'] = [0x02, mode, 0x0C, 0x00, 0x00, 0x00, 0x00, 0x00]
		PID_dict['speed'] = [0x02, mode, 0x0D, 0x00, 0x00, 0x00, 0x00, 0x00]
		PID_dict['timing_advance'] = [0x02, mode, 0x0E, 0x00, 0x00, 0x00, 0x00, 0x00]
		PID_dict['intake_air_temp'] = [0x02, mode, 0x0F, 0x00, 0x00, 0x00, 0x00, 0x00]
		PID_dict['MAF_flow'] = [0x02, mode, 0x10, 0x00, 0x00, 0x00, 0x00, 0x00]
		PID_dict['throttle_position'] = [0x02, mode, 0x11, 0x00, 0x00, 0x00, 0x00, 0x00]
		PID_dict['secondary_air_status'] = [0x02, mode, 0x12, 0x00, 0x00, 0x00, 0x00, 0x00]
		PID_dict['oxygen_present'] = [0x02, mode, 0x13, 0x00, 0x00, 0x00, 0x00, 0x00]
		PID_dict['oxy_b1_s1'] = [0x02, mode, 0x14, 0x00, 0x00, 0x00, 0x00, 0x00]
		PID_dict['oxy_b1_s2'] = [0x02, mode, 0x15, 0x00, 0x00, 0x00, 0x00, 0x00]
		PID_dict['oxy_b1_s3'] = [0x02, mode, 0x16, 0x00, 0x00, 0x00, 0x00, 0x00]
		PID_dict['oxy_b1_s4'] = [0x02, mode, 0x17, 0x00, 0x00, 0x00, 0x00, 0x00]
		PID_dict['oxy_b2_s1'] = [0x02, mode, 0x18, 0x00, 0x00, 0x00, 0x00, 0x00]
		PID_dict['oxy_b2_s2'] = [0x02, mode, 0x019, 0x00, 0x00, 0x00, 0x00, 0x00]
		PID_dict['oxy_b2_s3'] = [0x02, mode, 0x01A, 0x00, 0x00, 0x00, 0x00, 0x00]
		PID_dict['oxy_b2_s4'] = [0x02, mode, 0x01B, 0x00, 0x00, 0x00, 0x00, 0x00]
		PID_dict['obd_standard_id'] = [0x02, mode, 0x1C, 0x00, 0x00, 0x00, 0x00, 0x00]
		PID_dict['oxygen_sensor_present'] = [0x02, mode, 0x1D, 0x00, 0x00, 0x00, 0x00, 0x00]
		PID_dict['aux_input_status'] = [0x02, mode, 0x1E, 0x00, 0x00, 0x00, 0x00, 0x00]
		PID_dict['engine_run_time'] = [0x02, mode, 0x1F, 0x00, 0x00, 0x00, 0x00, 0x00]
		PID_dict['pids_support_21_40'] = [0x02, mode, 0x20, 0x00, 0x00, 0x00, 0x00, 0x00]
		PID_dict['distance_traveled_MIL'] = [0x02, mode, 0x21, 0x00, 0x00, 0x00, 0x00, 0x00]
		PID_dict['fuel_rail_pressure'] = [0x02, mode, 0x22, 0x00, 0x00, 0x00, 0x00, 0x00]
		PID_dict['fuel_rail_pressure_diesel'] = [0x02, mode, 0x23, 0x00, 0x00, 0x00, 0x00, 0x00]
		PID_dict['VO2S1_WR_lambda'] = [0x02, mode, 0x24, 0x00, 0x00, 0x00, 0x00, 0x00]
		PID_dict['VO2S2_WR_lambda'] = [0x02, mode, 0x25, 0x00, 0x00, 0x00, 0x00, 0x00]
		PID_dict['VO2S3_WR_lambda'] = [0x02, mode, 0x26, 0x00, 0x00, 0x00, 0x00, 0x00]
		PID_dict['VO2S4_WR_lambda'] = [0x02, mode, 0x27, 0x00, 0x00, 0x00, 0x00, 0x00]
		PID_dict['VO2S5_WR_lambda'] = [0x02, mode, 0x28, 0x00, 0x00, 0x00, 0x00, 0x00]
		PID_dict['VO2S6_WR_lambda'] = [0x02, mode, 0x29, 0x00, 0x00, 0x00, 0x00, 0x00]
		PID_dict['VO2S7_WR_lambda'] = [0x02, mode, 0x2A, 0x00, 0x00, 0x00, 0x00, 0x00]
		PID_dict['VO2S8_WR_lambda'] = [0x02, mode, 0x2B, 0x00, 0x00, 0x00, 0x00, 0x00]
		PID_dict['ERG'] = [0x02, mode, 0x2C, 0x00, 0x00, 0x00, 0x00, 0x00]
		PID_dict['ERG_error'] = [0x02, mode, 0x2D, 0x00, 0x00, 0x00, 0x00, 0x00]
		PID_dict['evaporative_purge'] = [0x02, mode, 0x2E, 0x00, 0x00, 0x00, 0x00, 0x00]
		PID_dict['fuel_level'] = [0x02, mode, 0x2F, 0x00, 0x00, 0x00, 0x00, 0x00]
		PID_dict['warm_up_attemps_since_clear'] = [0x02, mode, 0x30, 0x00, 0x00, 0x00, 0x00, 0x00]
		PID_dict['distance_traveled_since_clear'] = [0x02, mode, 0x31, 0x00, 0x00, 0x00, 0x00, 0x00]
		PID_dict['evap_vapour_pressure'] = [0x02, mode, 0x32, 0x00, 0x00, 0x00, 0x00, 0x00]
		PID_dict['baromatic_pressure'] = [0x02, mode, 0x33, 0x00, 0x00, 0x00, 0x00, 0x00]
		PID_dict['CO2S1_WR_lambda'] = [0x02, mode, 0x34, 0x00, 0x00, 0x00, 0x00, 0x00]
		PID_dict['CO2S2_WR_lambda'] = [0x02, mode, 0x35, 0x00, 0x00, 0x00, 0x00, 0x00]
		PID_dict['CO2S3_WR_lambda'] = [0x02, mode, 0x36, 0x00, 0x00, 0x00, 0x00, 0x00]
		PID_dict['CO2S4_WR_lambda'] = [0x02, mode, 0x37, 0x00, 0x00, 0x00, 0x00, 0x00]
		PID_dict['CO2S5_WR_lambda'] = [0x02, mode, 0x38, 0x00, 0x00, 0x00, 0x00, 0x00]
		PID_dict['CO2S6_WR_lambda'] = [0x02, mode, 0x39, 0x00, 0x00, 0x00, 0x00, 0x00]
		PID_dict['CO2S7_WR_lambda'] = [0x02, mode, 0x3A, 0x00, 0x00, 0x00, 0x00, 0x00]
		PID_dict['CO2S8_WR_lambda'] = [0x02, mode, 0x3B, 0x00, 0x00, 0x00, 0x00, 0x00]
		PID_dict['catalyst_temp_B1S1'] = [0x02, mode, 0x3C, 0x00, 0x00, 0x00, 0x00, 0x00]
		PID_dict['catalyst_temp_B2S1'] = [0x02, mode, 0x3D, 0x00, 0x00, 0x00, 0x00, 0x00]
		PID_dict['catalyst_temp_B1S2'] = [0x02, mode, 0x3E, 0x00, 0x00, 0x00, 0x00, 0x00]
		PID_dict['catalyst_temp_B2S2'] = [0x02, mode, 0x3F, 0x00, 0x00, 0x00, 0x00, 0x00]
		PID_dict['pids_support_41_60'] = [0x02, mode, 0x40, 0x00, 0x00, 0x00, 0x00, 0x00]
		PID_dict['monitor_status_drive_cycle'] = [0x02, mode, 0x41, 0x00, 0x00, 0x00, 0x00, 0x00]
		PID_dict['control_module_voltage'] = [0x02, mode, 0x42, 0x00, 0x00, 0x00, 0x00, 0x00]
		PID_dict['absolute_load'] = [0x02, mode, 0x43, 0x00, 0x00, 0x00, 0x00, 0x00]
		PID_dict['command_equivalence_ratio'] = [0x02, mode, 0x44, 0x00, 0x00, 0x00, 0x00, 0x00]
		PID_dict['relative_throttle_position'] = [0x02, mode, 0x45, 0x00, 0x00, 0x00, 0x00, 0x00]
		PID_dict['ambient_air_temp'] = [0x02, mode, 0x46, 0x00, 0x00, 0x00, 0x00, 0x00]
		PID_dict['absolute_throttle_position_B'] = [0x02, mode, 0x47, 0x00, 0x00, 0x00, 0x00, 0x00]
		PID_dict['absolute_throttle_position_C'] = [0x02, mode, 0x48, 0x00, 0x00, 0x00, 0x00, 0x00]
		PID_dict['absolute_throttle_position_D'] = [0x02, mode, 0x49, 0x00, 0x00, 0x00, 0x00, 0x00]
		PID_dict['absolute_throttle_position_E'] = [0x02, mode, 0x4A, 0x00, 0x00, 0x00, 0x00, 0x00]
		PID_dict['absolute_throttle_position_F'] = [0x02, mode, 0x4B, 0x00, 0x00, 0x00, 0x00, 0x00]
		PID_dict['command_throttle_actuator'] = [0x02, mode, 0x4C, 0x00, 0x00, 0x00, 0x00, 0x00]
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

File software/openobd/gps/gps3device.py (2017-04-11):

from location.location import Location
from gps.igpsdevice import IGPSDevice
#from gps3 import gps3
import os
import datetime
import serial
import time

class GPS3Device(IGPSDevice):
    """Concrete GPS device using gps3"""

    def __init__(self):
        self.location = None
        self.longitude = None
        self.latitude = None
        self.altitude = None
        self.modem = None
        self.GPSStatus = None
        #self.gps_socket = None
        #self.data_stream = None
        self._ready = False

    def initialize(self):
        self.modem = serial.Serial("/dev/ttyAMA0", baudrate=115200)
        powerup = "AT+CGNSPWR=1\r"
        self.modem.write(powerup.encode())
        self.modem.readline()
        self.GPSStatus = self.modem.readline()
        time.sleep(2)
        #os.system('sudo gpsd /dev/ttyAMA0 -F /var/run/gpsd.sock')
        #self.gps_socket = gps3.GPSDSocket()
        #self.data_stream = gps3.DataStream()
        #self.gps_socket.connect()
        #self.gps_socket.watch()
        self._ready = True

    @property
    def status(self) -> bool:
        return self._ready

    def getDataStream(self):
        request = "AT+CGNSINF\r"
        self.modem.write(request.encode())
        self.modem.readline()
        data = self.modem.readline().decode()
        if data.startswith("+CGNSINF"):
            data = data.split(",")
            #print(data)
            if data[1]=='0':
                #Latitude ±dd.dddddd [-90.000000,90.000000]
                self.latitude = 0.0
                #Longitude ±ddd.dddddd [-180.000000,180.000000]
                self.longitude = 0.0
                #Altitude 0-120m
                self.altitude = 0.0
            else:
                #Latitude ±dd.dddddd [-90.000000,90.000000]
                self.latitude = data[3].strip()
                #Longitude ±ddd.dddddd [-180.000000,180.000000]
                self.longitude = data[4].strip()
                #Altitude 0-120m
                self.altitude = data[5].strip()

    def read_location(self) -> Location:
        """Return the same location each time"""
        self.getDataStream()
        while(self.longitude == None):
            self.getDataStream()
        time = datetime.datetime.now()
        self.location = Location(float(self.latitude), float(self.longitude), float(self.altitude), time)
        return self.location

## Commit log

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2016-11-09 added hardware schematic file (not complete)
    [first_prototype.sch]
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2016-11-15 Fixed gyro temp and accel
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2016-11-15 pushing changes to schematics
    [first_prototype.brd, first_prototype.sch]
2016-11-17 adding experimental port to RPi of mcp_can c++ driver (code from seeedstudio)
2016-11-23 update to hardware to-do list
    [first_prototype.brd]
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2016-12-29 changes to schematics
    [CAN_Node2pi.sch]
2017-01-02 type hinting and renamed section to device for config
2017-01-03 adds mockfixedgpsdevice, app can read both mock temperature and location
2017-01-04 fixed relative imports and paths
    [gps3device.py]
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2017-01-14 fix to gps again
    [gps3device.py]
2017-01-14 fixed os set up
    [gps3device.py, obddevice.py]
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2017-01-19 Added PCBproject plus BOM in documentation
    [CanNode.PcbLib, CanNode.PrjPcb, CanNode.SchDoc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]
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2017-01-20 schematic files for all parts. todo list reformat
    [LevelConverter.SchDoc, MPU6050.SchDoc, PowerCircuit.SchDoc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]
2017-01-20 actually added schematics
    [CanNode.PrjPcb, LevelConverter.SchDoc, MPU6050.SchDoc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]
2017-01-20 almost done CAN controller schematic
    [CanNode.SchDoc, CanNode.SchLib]
2017-01-20 Add MPU-6050 components and individual libraries"
    [CanNode.PcbLib, CanNode.PrjPcb, CanNode.SchLib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]
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2017-01-20 sim808 library done
    [CanNode.SchDoc, SIM808.PcbLib, SIM808.SchLib]
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2017-01-24 mpu6050 schematic done
    [MPU6050.SchDoc, MPU6050.SchLib]
2017-01-24 Added power supply schematic
    [CanNode.PrjPcb, CanNode.SchDoc, PowerCircuit.SchDoc]
2017-01-24 added ports to MPU6050 schematic
    [MPU6050.SchDoc]
2017-01-24 removed old eagle file
    [CAN_Node2pi.sch]
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2017-01-25 preliminary sim808 schematic
    [CanNode.SchDoc, CanNode.SchLib, SIM808.SchDoc]
2017-01-27 some small updates to sim808 schematic
    [CanNode.PrjPcb, SIM808.SchDoc]
2017-01-28 power supply complete
    [PowerCircuit.PcbLib, PowerCircuit.SchDoc, PowerCircuit.SchLib]
2017-01-28 Power circuit done
    [PowerCircuit.SchDoc, PowerCircuit.SchLib]
2017-01-28 updated .gitignore
    [LD39100PUR.PcbLib, LD39100PUR.SchLib]
2017-01-28 power converter for gsm chip + footprint
    [LD39100PUR.PcbLib, LD39100PUR.SchLib, SIM808.SchDoc]
2017-01-28 CanNode schematic and footprint done
    [CanNode.PcbLib, CanNode.SchDoc, CanNode.SchLib]
2017-01-29 808 done
    [CanNode.PrjPcb, CanNode.SchDoc, LD39100PUR.PcbLib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]
2017-01-29 All sch done but antennae
    [CanNode.PcbLib, CanNode.SchDoc, CanNode.SchLib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]
2017-01-30 added antenna footprint,schematic libs
    [uFLAntenna.PcbLib, uFLAntenna.SchLib]
2017-01-30 added pins for antenna schematic lib
    [uFLAntenna.SchLib]
2017-01-30 uFl fixed
    [CanNode.PrjPcb, PowerCircuit.SchDoc, uFLAntenna.PcbLib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]
2017-01-31 started pcb layout
    [mainPCB.PcbDoc, uFLAntenna.PcbLib, uFLAntenna.SchLib]
2017-01-31 update to pcb
    [mainPCB.PcbDoc]
2017-01-31 changes to cannode.prj
    [CanNode.PrjPcb]
2017-01-31 started sim808 layout
    [mainPCB.PcbDoc]
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2017-02-01 added PCB design rules
    [CanNode.PrjPcb, SIM808.SchDoc, mainPCB.PcbDoc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]
2017-02-02 Layout: Ground plane and signals remaining
    [CanNode.PcbLib, CanNode.SchDoc, CanNode.SchLib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]
2017-02-03 routed connections to rpi header, grounds. updated to-do (README)
    [mainPCB.PcbDoc]
2017-02-03 small edits to routing
    [mainPCB.PcbDoc]
2017-02-03 PCB done!
    [CanNode.PrjPcb, PowerCircuit.PcbLib, SIM808.SchDoc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]
2017-02-03 fixed PCB errors
    [CanNode.PcbLib, MPU6050.PcbLib, mainPCB.PcbDoc]
2017-02-04 exported csv bill of materials to hardware/documentation
    [mainPCB.csv]
2017-02-06 550um vias
    [mainPCB.PcbDoc]
2017-02-06 generated gerber and drill files
    [CanNode.PrjPcb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]
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2017-02-11 added image of pcbs
    [CanNode.PrjPcb]
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2017-02-14 fixe accerometer reading 0
    [obddevice.py]
2017-02-17 removed useless sch file
    [LevelConverter.SchDoc]
2017-02-27 corrects typo in app.py
    [mockobddevice.py]
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2017-03-04 added bmp280 pressure sensor schematic and python code
    [bmp280_i2c.PcbLib, bmp280_i2c.SchDoc, bmp280_i2c.SchLib]
2017-03-04 attiny done
    [ATtiny.PcbLib, ATtiny.SchDoc, ATtiny.SchLib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]
2017-03-04 fixed some errors
    [CanNode.PrjPcb, bmp280_i2c.SchDoc, bmp280_i2c.SchLib]
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2017-03-11 added new components to PCB layout. most routing done.
    [CanNode.PrjPcb, bmp280_i2c.PcbLib, bmp280_i2c.SchDoc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]
2017-03-11 finished routing. added expansion port including i2c, 3v3, 5v0, gnd ports.
    [mainPCB.PcbDoc]
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2017-03-12 PCB ground fixed
    [ATtiny.SchDoc, mainPCB.PcbDoc]
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2017-03-12 pcb ready for round 2
    [CanNode.PrjPcb, MPU6050.SchDoc, mainPCB.PcbDoc]
2017-03-12 pcb: added tp and redone psu
    [mainPCB.PcbDoc]
2017-03-12 added 24V psu schematic + 2nd pcb version
    [CanNode.PrjPcb, PowerCircuit.PcbLib, PowerCircuit.SchLib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]
2017-03-13 psu plygon and vias remaining
    [CanNode.PrjPcb, CanNode.SchDoc, PowerCircuit.PcbLib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]
2017-03-13 PCB Done! for reallz!
    [CanNode.PrjPcb, PowerCircuit.PcbLib, PowerCircuit.SchLib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]
2017-03-13 generated gerber files for PCB production
    [CanNode.PrjPcb, mainPCB_24V.PcbDoc]
2017-03-13 fixed missing properties in gerber files
    [CanNode.PrjPcb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]
2017-03-14 finalized gerber files
    [CanNode.PrjPcb, mainPCB_24V.PcbDoc]
2017-03-16 cleaned up hardware directory structure a bit. updated README to be more informative.
    [ATtiny.PcbLib, ATtiny.SchDoc, ATtiny.SchLib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]
2017-03-16 removed old hardware documentation folder (to be replaced) and some other unecessary folders
    [mainPCB.csv]
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2017-04-01 adds volt and baro code for config and deviceconstants, fixes test_location
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2017-04-01 manager does not need to join workers because they are daemon threads
2017-04-05 refactors manager to have only one worker method that can be reused for each thread with different read methods and sleep intervals
2017-04-05 refactors manager to replace multiple printing methods with one method print_accumulator_mean
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2017-04-25 added schematics as images, pdf
    [SIM808.dxf, mainPCB_24V.PcbDoc, mainPCB_24V_placement helper.PcbDoc]
2017-04-25 added BOM
    [BOM.xls]
